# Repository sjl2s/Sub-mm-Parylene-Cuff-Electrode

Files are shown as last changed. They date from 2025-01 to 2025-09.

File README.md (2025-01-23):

# Sub-mm-Parylene-Cuff-Electrode
An electrode for interfacing with sub-mm diameter nerves for recording and stimulation, manufactured out of Parylene C
 # About

A nerve cuff for sub-millimeter diameter branch nerves designed and manufatured for CARSS by the [Biomedical Microsystems Lab at USC](https://biomems.usc.edu/). It is fabricated out of thin-film Parylene C with platinum electrodes and contacts, and contains a unique design and three dimensional geometry for surgical placement. The cuff is manufactured using thin-film Parylene C and platinum, followed by thermoforming into the desired shape.



Process flow diagram

# Disclaimer
The contents of this repository are subject to revision. No representation or warranty, express or implied, is provided in relation to the accuracy, correctness, completeness, or reliability of the information, opinions, or conclusions expressed in this repository.

The contents of this repository (the “Materials”) are experimental in nature and should be used with prudence and appropriate caution. Any use is voluntary and at your own risk.

The Materials are made available “as is” by USC (the University of Southern California and its trustees, directors, officers, employees, faculty, students, agents, affiliated organizations and their insurance carriers, if any), its collaborators Med-Ally LLC and Medipace Inc., and any other contributors to this repository (collectively, “Providers”). Providers expressly disclaim all warranties, express or implied, arising in connection with the Materials, or arising out of a course of performance, dealing, or trade usage, including, without limitation, any warranties of title, noninfringement, merchantability, or fitness for a particular purpose.

Any user of the Materials agrees to forever indemnify, defend, and hold harmless Providers from and against, and to waive any and all claims against Providers for any and all claims, suits, demands, liability, loss or damage whatsoever, including attorneys' fees, whether direct or consequential, on account of any loss, injury, death or damage to any person or (including without limitation all agents and employees of Providers and all property owned by, leased to or used by either Providers) or on account of any loss or damages to business or reputations or privacy of any persons, arising in whole or in part in any way from use of the Materials or in any way connected therewith or in any way related thereto.

The Materials, any related materials, and all intellectual property therein, are owned by Providers.

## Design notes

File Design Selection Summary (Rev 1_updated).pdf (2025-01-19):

# NEST 4 – Design Selection

Revised 22 June 2023

This document describes the design choices for the microfabricated cuff electrode. The lead (developed by Med-Ally) and insertion tool are not included in this document.

The document begins with design requirements and decisions made based on those requirements, follows with detailed mechanical design options and the selection process, and ends with an outline of planned testing (which will be further developed in Y2).

## 1 DESIGN REQUIREMENTS

The following design requirements were set for the microfabricated cuff design:

1. All materials must be biocompatible and have a history of chronic in vivo use
2. Cuff must fit a target nerve of 0.5-1.0 mm diameter
3. Cuff must wrap at least 1.5x around nerve diameter
4. Cuff must be self-sizing (within ranges below)
a. Small size: 0.5-0.8 mm diameter
b. Large size: 0.7-1.0 mm diameter
5. Electrodes must be spaced to allow for efficient stimulation
6. Electrodes and traces must be sized to allow for typical stimulation parameters (based on vagus nerve stimulation values)

To achieve each of these requirements, the following design decisions were made:

1.1 MATERIAL SELECTION
The microfabricated cuff is made of Parylene C as the backbone and insulation material and platinum as the conductive material. Both materials are compatible with existing, well-established microfabrication techniques, are biocompatible, and have been used extensively in chronic implants. The Med-Ally leads (as used in all NESTs and described in NEST 3) are made entirely of biocompatible materials and are attached to the microfabricated cuff either using a welding/bonding process (which does not add any additional material) or using biocompatible silver epoxy (Epo-TEK MED H20E). The connection point is insulated with medical grade silicone or epoxy.

1.2 CUFF DIMENSIONS
Helical electrodes and circumferential electrodes were considered. The electrode height (see figure below) for each cuff size was selected to allow the electrode to wrap 1.5 times around the largest nerve diameter in the size range. For helical electrode designs, the angle of the electrode was selected to ensure the cuff did not overlap itself (electrode turn gap > 0 in the figure below) when wrapped around any nerve diameter in the size range. The electrode width was defined by stimulation requirements (described later in this section).

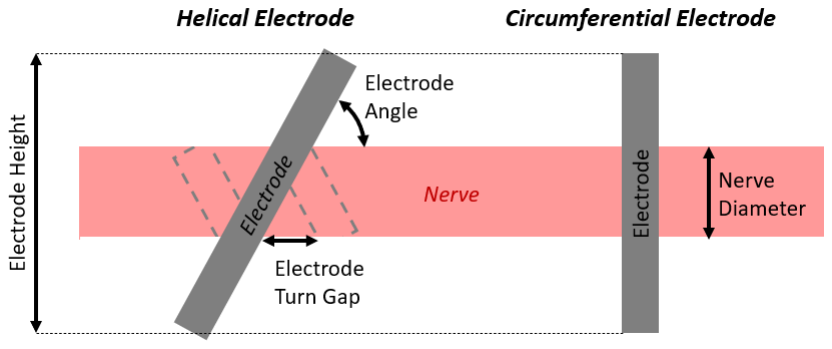
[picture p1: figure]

1.3 SELF-SIZING PROPERTY
The backbone material, Parylene C, is a thermoplastic polymer, allowing it to be thermoformed and permanently hold a 3D shape. Parylene C is also flexible, allowing it to be manually and temporarily flexed out of its formed shape. The microfabricated cuff electrode is thermoformed into a cuff shape matching the smallest diameter in the corresponding size range (i.e. 0.5 mm for small, 0.7 mm for large). After thermoforming, the cuff can be manually expanded to a larger size, then closes back to its original size when released. When expanded and placed on the nerve (with diameter greater than or equal to the cuff), the cuff closes until it contacts the nerve.

1.4 ELECTRODE SPACING
The distance between electrodes was set based on recommendations from experts in the field, literature on ideal electrode spacing, and geometry of existing larger cuff electrodes. In general, the ideal distance between electrodes is proportional to nerve diameter, so the electrode spacing found in the existing Liva Nova cuff (9 mm spacing for 2 mm diameter nerve) was scaled down to fit the target nerve diameters for the microfabricated cuff (3 mm spacing for 0.5-0.8 mm diameter nerve; 4 mm spacing for 0.7-1.0 mm diameter nerve).

1.5 ELECTRODE SIZE
The surface area of the electrodes was dictated by charge injection limits and desired stimulation parameters. Based on research summarized below, a charge storage capacity of 100 μC/cm² was used to calculate required electrode surface area. If this is not achieved with bare thin film Pt, electrode size can be later increased or charge storage capacity can be increased with surface treatments such as roughening, electroplating, or deposition of conductive polymers.
- Typical stimulation parameters for VNS
- 0.5-4.2 mA at 100 μs [1]
- 1.25-2.25 mA at 250 μs [2]
- 0.3-2.4 mA at 300 μs [1]
- 0.2-2.0 mA at 500 μs [1]
- Maximum allowable stimulation for LivaNova VNS: 3.5 mA, 1000 μs [3], [4]
- Charge injection capacity for platinum
- Foil

- 35-200 μC/cm²
[5]
- 50-100 μC/cm² at 0.2 ms (charge balanced biphasic) [6]
- Thin film
- 170 μC/cm² at 0.2 ms [7]
- 260 μC/cm² at 0.75-1.0 ms [7]
- Charge injection limits for tissue
- 50-100 μC/cm²
[internal recommendation]
- Shannon limit - dependent on electrode area [8]
- 200 μm circular electrode: 317 μC/cm²
- 600 μm x 2000 μm rectangular electrode: 51 μC/cm²

1.6 ELECTRODE SHAPE
Rather than using one large rectangular electrode, an array of closely packed, shorted microelectrodes was used. This prevents the high likelihood of cracking in the large electrode area during handling or stimulation by reducing the size of the large metal area and adding open areas in the electrode where the top and bottom Parylene layers can adhere to each other.

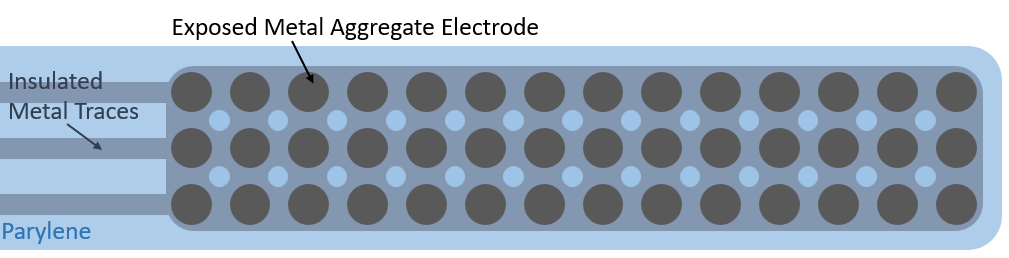
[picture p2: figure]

Based on the typical VNS parameters listed in the previous paragraph and a charge storage capacity of 100 μC/cm²
, the required electrode area and number of subelectrodes was calculated:
VNS Stimulation Parameters | Charge Per Phase | Required Electrode Area | Number of Microelectrodes
Amplitude | Pulse Width | | | 200 µm Diameter | 300 µm Diameter
4.2 mA | 100 µs | 0.42 µC | 0.42 mm² | 14 | 6
2.25 mA | 250 µs | 0.56 µC | 0.56 mm² | 18 | 8
2.4 mA | 200 µs | 0.72 µC | 0.72 mm² | 23 | 11
2.0 mA | 500 µs | 1.00 µC | 1.00 mm² | 32 | 15

The maximum values (italicized) were used to select the number of microelectrodes, and a safety factor of at least 1.5 was used.

For helical electrodes, a width of 3 and 4 microelectrodes (small and large sizes) was selected as it allows for a moderate helix angle (55°) without any electrode overlap at the smallest nerve size and produces sufficient electrode area when wrapped ~1.5x around the nerve.

- Small cuff (0.5-0.8 mm dia): 3x18 200 μm microelectrodes (1.70 mm²
total area)
- Large cuff (0.7-1.0 mm dia): 4x22 200 μm microelectrodes (2.77 mm² total area)

For circumferential electrodes, the minimum nerve circumference dictated the electrode layout (electrodes were wider due to the overlapping arms of the electrodes blocking part of the stimulation area).

- Small cuff (0.5-0.8 mm dia): 9x14 200 μm microelectrodes (1.70 mm²

total area, 1.56 mm²
contact area with smallest nerve)
- Large cuff (0.7-1.0 mm dia): 6x18 200 μm microelectrodes (3.39 mm²

total area, ~1.60 mm² area in contact with smallest nerve)

1.7 TRACE WIDTH
The minimum allowable trace width (to prevent overheating) was dictated by maximum current requirements and calculated using a PCB trace width calculator (with formulas sourced from IPC-2221). A total minimum trace width of 72 µm was calculated (from parameters: 4.2 mA, 200 nm trace thickness, 10 °C rise at 37 °C ambient temperature). Four connected, parallel 36 µm traces with intermittent bridges between them are used to maintain device flexibility and add in a safety factor of 2, still with sufficient width if two traces are broken.

## 2 MECHANICAL DESIGN OPTIONS

There are numerous mechanical designs which would meet the device requirements. Several experts in the field stated no preference on backbone and electrode shape for surgical, anatomical, or electrochemical considerations. To select a mechanical design, several designs were fabricated and tested to determine the best option for fabrication, surgical handling, and potential failure modes. The design options are described in this section; details on the fabricated designs and testing protocol is described later in this document.

The microfabricated cuff has three regions: the backbone, the tail, and the lead. As shown in the image below, the backbone is the main body of the device which holds the electrodes and forms the cuff architecture, the tail extends from the backbone and connects the electrodes to the lead with insulated traces, and the lead attaches to the traces at the end of the tail at the lead attachment point.

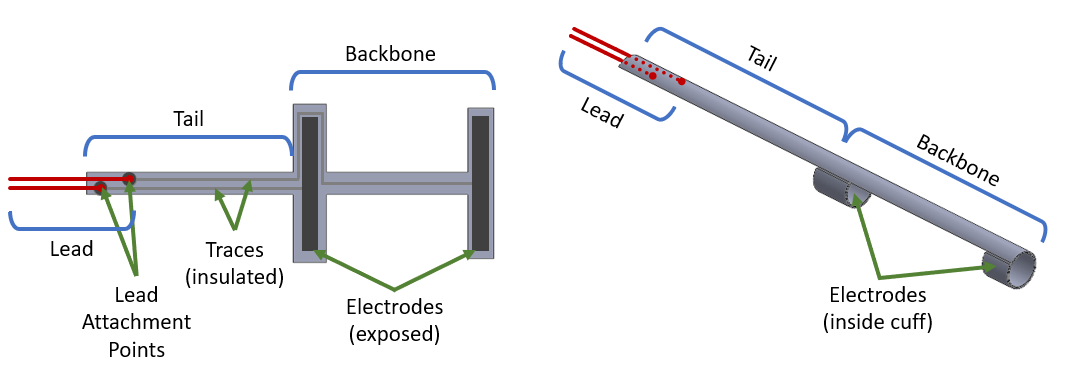
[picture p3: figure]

Note: In all images in the remainder of this section, the shape of the flat electrode array (as it is fabricated) is shown on the left, and the electrode array after thermoforming into shape is shown on the right. Only the Parylene is shown in these images, the electrodes are not drawn in.

2.1 PARYLENE BACKBONE DESIGNS
The Parylene backbone is the main part of the device which supports the electrodes. It is microfabricated in a flat configuration on a carrier wafer and then thermoformed into the cuff shape. The considered designs are shown here with basic notes pointing out their main features.

Note: the images in this section only show the backbone portion of the device, not the tail portion.

2.1.1 Design A: U-Shaped
Design A not considered for final design
- Dual helical cuff (opposite directions)
| ○ Similar to design B, but with center Parylene bridge at the bottom of the electrodes
2.1.2 | Design B: I-Shaped (tilted, opposite)
- Dual helical cuff (opposite directions)
- 360°+ electrode coverage over a ~1.5-3 mm span (single helical cuff width)

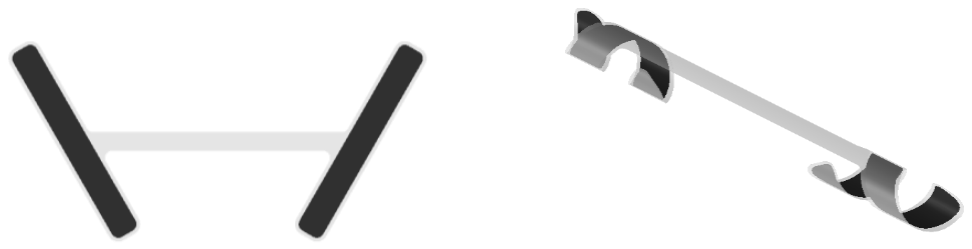
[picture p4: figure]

2.1.3 Design C: I-Shaped (tilted, same)
- Dual helical cuff (same direction)
- 360°+ electrode coverage over a ~1.5-3 mm span (single helical cuff width)

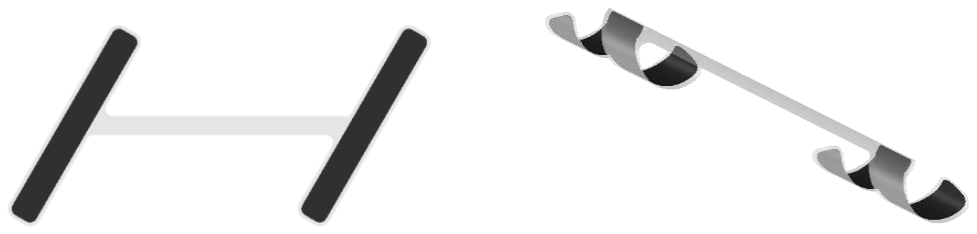
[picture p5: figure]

2.1.4 Design D: I-shaped (straight)
- Dual circumferential cuff
- ~335° electrode coverage over a ~0.5-1 mm span (electrode width)

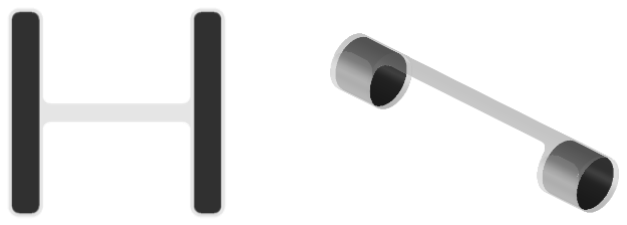
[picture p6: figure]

2.1.5 Design E: Full cuff
- Single circumferential cuff with 2 isolated electrodes
- ~355° electrode coverage over a ~0.5-1 mm span (electrode width)

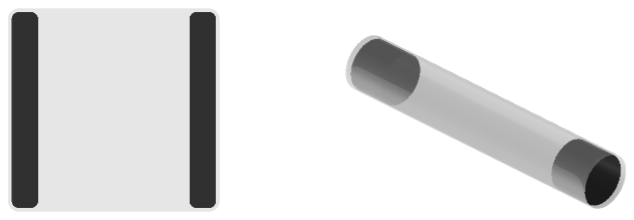
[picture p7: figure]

2.2 CABLE ROUTING DESIGNS
To connect the electrodes to the lead, a tail must be attached to the backbone to connect metal traces from each electrode to a bondpad which connects to the lead. The tail must have some length (~2 cm) and slack to allow for motion during the implantation procedure and any motion of the nerve relative to the point where the lead is anchored. The considered tail options are listed here with some potential issues and advantages.

Note: All cable options are shown on backbone design B, but can be applied to any design

2.2.1 Tail 1: End
Tail 1 not considered for final design
- Tail extending straight from one end
- No strain relief or slack

2.2.2 Tail 2: Centered
- Any torque on tail will be centered on cuff
- Difficult to implement with fins or full cuff designs

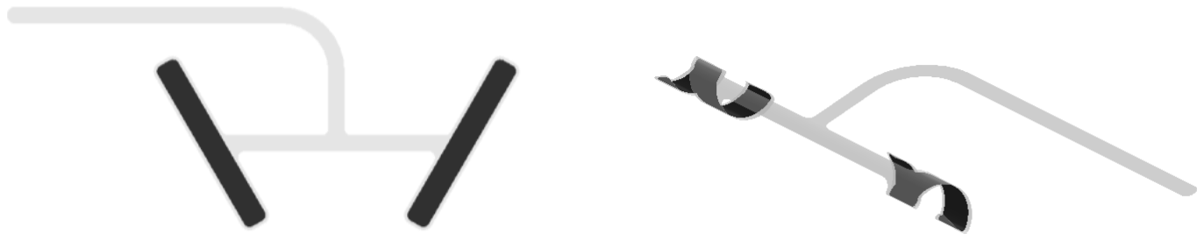
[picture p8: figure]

2.2.3 Tail 3: U-turn
- Prevents torque by adding more slack (service loop)

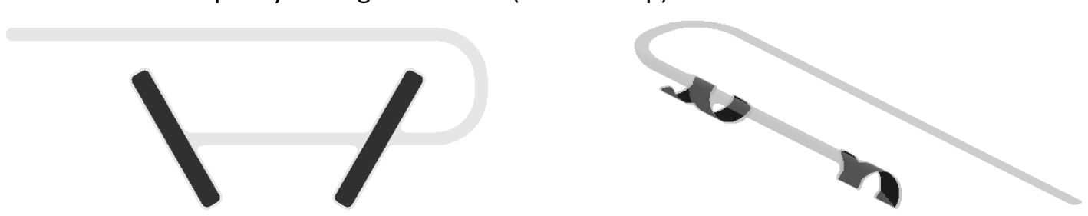
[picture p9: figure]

2.2.4 Optional Serpentine Strain Relief
- Auxetic structure to allow stretching
- Could be added at any point in the tail

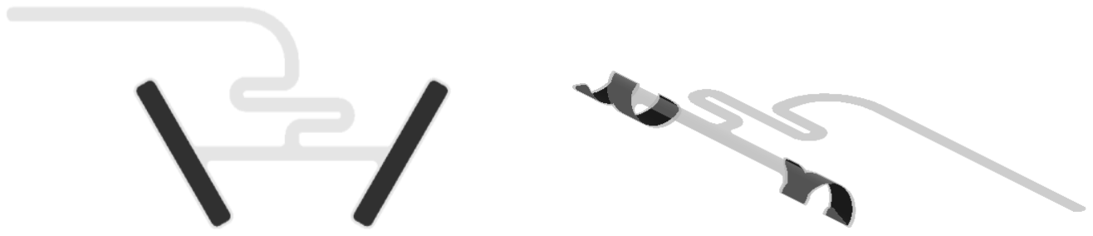
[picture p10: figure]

2.3 NERVE INSULATION
Insulation of the nerve between the electrodes is critical to constrain the electric field during stimulation. Insulation can be done either with Parylene (fabricated with the rest of the cuff) or PDMS (either a separate cuff added at the end or molded onto the Parylene backbone). Several options (listed here) were considered for nerve insulation.

2.3.1 Solid Parylene
- Design E: Full cuff

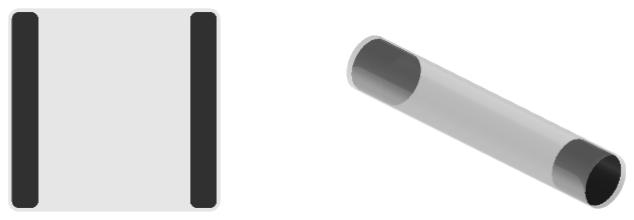
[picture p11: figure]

2.3.2 Parylene Fins
- Designs A-D: Parylene fins added between electrodes
- More mechanically flexible than solid Parylene cuff
- E-field leakage between the fins

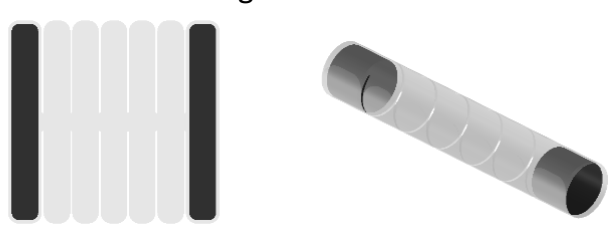
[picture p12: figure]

2.3.3 PDMS Insulation
- Separate molded PDMS cuff (can be attached to Parylene or added separately after
| implantation)
- PDMS can be solid (with any Parylene design) or with fins (with designs A-D)
- E-field leakage if fins are used

## 3 MECHANICAL DESIGN SELECTION

3.1 DESIGNS TO TEST
The large number of design combinations could not be exhaustively tested, so a subset of 8 designs which spanned all backbone shapes, tails, and other features were selected. Designs are numbered using the following component labels (crossed out designs were not considered):
Backbone | Tail | Other Feature
(A) U-shaped | (1) End | (s) serpentine strain relief
(B) I-shaped (tilted/opposite) | (2) Centered | (f) fins
(C) I-shaped (tilted/same) | (3) U-turn | (-) none
(D) I-shaped (straight)
(E) Full cuff

The following designs were tested:

- B2-: I-shaped/tilted/opposite, centered tail
- B2s: I-shaped/tilted/opposite, centered tail with serpentine
- C2-: I-shaped/tilted/same, centered tail
- C3-: I-shaped/tilted/same, u-turn tail
- D2-: I-shaped/straight, centered tail
- D2f: I-shaped/straight with fins, centered tail
- D3f: I-shaped/straight with fins, u-turn tail
- E3-: Full cuff, u-turn tail

To evaluate backbone shape, compare: B2- vs. C2- vs. D2- vs. E3-

To evaluate tails, compare: C2- vs C3- and D2f vs D3f

To evaluate serpentine strain relief, compare: B2- vs B2s

To evaluate fins, compare: D2- vs D2f

3.2 DESIGN SELECTION PROTOCOL
The following testing protocol was used to rank each design and each component. 6 parts for each design were tested (n=6). Steps that may improve with repetition (fixturing for thermoforming, implanting) were tested in varying order for each iteration. Tests which were recorded and scored are labeled and bolded within the protocol.

3.2.1 Thin Film Fabrication
1. Fabricate dummy parts (no metal) using standard thin film processing
2. Using varying base layer annealing conditions (impacts the curvature of the device prior to
| thermoforming)
a. 60, 100, and 150 °C
b. Two parts for each annealing condition (total n=6) were processed in all remaining steps

3.2.2 Thermoforming
1. Release the parts from the carrier wafer
2. Fixture into a 0.5 mm cuff and thermoform at 200 °C for 12 hours
a. Test 1 (Fabrication Difficulty): Record the amount of time required to release the device
| from the wafer and fixture for thermoforming
i. A single trained operator thermoformed all parts within each annealing group to
| prevent data errors from variability between operators ii. Captures if any device geometries are difficult to work with
3. Remove parts from fixture

3.2.3 Visual Inspection
1. Inspect parts using a stereoscope (best magnification to visualize the full device - same scope
| and magnification was used for all devices)
2. Test 2a (Post-Thermoform Inspection - Shape): Calculate the fabrication yield for all devices of a
| given design, where devices that do not hold the fixtured shape are failures
a. Determines if any geometries are prone to thermoforming shape failures
3. Inspect parts using a 10x microscope at each of the inspection points shown below

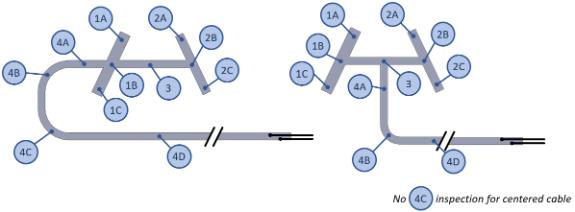
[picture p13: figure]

4. Test 2b (Post-Thermoform Inspection - Cracking): Count the total length of cracks in the Parylene in a 0.25x0.25 mm square area at each inspection point
a. Determines if any geometries are more prone to cracking during fabrication and at what location cracks are more common
b. Balances any errors in test 1 (i.e. if a part is fixtured quickly but badly, the good score in test 1 will be balanced by a bad score in test 2)

3.2.4 Evaluate Opening Force
1. Fixture parts with one end of cuff secured to load cell and one end secured to a micrometer
| stage
2. Use wires to fixture parts such that the cuff is able to open and close as it will in the
| implantation tools
3. Adjust the micrometer such that the cuff is opened to a 0.5 mm width (the thermoformed size)
| where the opening force is zero
4. Expand the cuff using the micrometer to 0.8, 1.2, 1.6, and 2.4 mm
5. Test 3a (Opening Force - Preliminary): Measure the force required to open the cuff to each of
| the listed micrometer readings
a. Proxy for cuff pressure measurements (pressure measurement setup not available at
| the time of testing)

6. Return the cuff to its closed form (0.5 mm), open to 2.4 mm, then close to 0.5 mm; repeat 18x (including the first measurement, this will be 19 cycles)
7. Expand the cuff using the micrometer (20th cycle) to 0.8, 1.2, 1.6, and 2.4 mm
8. Test 3b (Opening Force - Cycled): Measure the change in force required to open the cuff to each of the listed micrometer readings as compared to the first cycle
a. Proxy for cuff pressure measurements (pressure measurement setup not available at the time of testing)

3.2.5 Implant Cuff
1. Mount cuff onto an interim implantation tool (tweezers modified with wires)
a. Place cuff on flat surface
b. Close tweezers and thread tweezer tips into the center of the cuff
c. Open tweezers and align over nerve
d. Lower tweezers and close below the nerve, placing cuff
e. Retract tweezers out of cuff, open, and pull away from nerve
f. Adjust cuff (if needed) to close snugly around nerve
2. “Implant” (place) cuff onto a dummy nerve
a. For the dummy nerve, use a wet/overcooked rice noodle ~0.7-0.9 mm in diameter
b. Hold dummy nerve between two supports suspended 1 mm above a flat surface to
| simulate allowable space during surgery
3. Test 4 (Implantation Difficulty): Rank the devices from least to most difficult to implant
| * Note: The initial plan was to record the time required to implant the device, however timing was not consistent with the interim implantation tool, so a ranked qualitative comparison was used instead – see Appendix for details on testing * Note: This test was only performed on one set of devices – it did not accurately represent implantation difficulty because the surgical tool has not yet been developed and the interim tool was not consistent in use
a. Will capture if any device geometries are relatively more difficult to implant
b. A single trained operator performed the simulated implant on all parts within each
| annealing group to prevent data errors from variability between operators
3.2.6 | Simulate Body Movement
1. Simulate stress on device during surgery by pulling tail perpendicular and parallel to the nerve
2. Simulate stress on device during body movement by stretching the nerve along and
| perpendicular to its length
3. Test 5 (Cuff Movement): Measure the distance the cuff moves during the simulated stress
| * Note: Due to difficulties in performing test 4, cuff movement was observed qualitatively instead of quantitatively; quantitative measurements will be taken with future device generations once a more reliable surgical tool has been developed * Note: This test was only performed on one set of devices due to the constraint with the implantation tool described under test 4
a. Determines if any device geometries are prone to shifting out of place during or after
| implantation

3.2.7 Repeat Visual Inspection
1. Test 6a (Post-Implantation Inspection - Shape): Calculate the shape yield for all devices of a
| given design, where devices that do not hold the fixtured shape are failures
a. Determines if any geometries are prone to shape failures during surgical handling
2. Test 6b (Post-Implantation Inspection - Cracking): Count the total length of cracks in the
| Parylene in a 0.25x0.25 mm square area at each inspection point, and subtract the initial inspection length from test 2b
a. Determines if any geometries are more prone to cracking during surgical handling

3.2.8 Failure Testing
1. Mount cuff on nerve underneath the load cell, then pull the tail end perpendicular to the nerve
| until failure (n=2 per design)
2. Test 7a (Pull Failure - Perpendicular): Measure the force at failure and record the failure point
3. Mount cuff on nerve underneath the load cell, then pull the tail end parallel to the nerve in the
| direction of the tail until failure (n=2 per design)
4. Test 7b (Pull Failure - Parallel): Measure the force at failure and record the failure point

3.3 SCORE CALCULATIONS
Results of each test were scaled to produce a score from 0 to 1 for each tested device and each design component, with 0 being the worst score and 1 being the best score. Tests were also weighted, with higher weights given to more important or more significant tests. Details of how scores were calculated and weights were selected are below:

Test 1: Fabrication Difficulty

Design Score = 1 −

| avg fixturing time (single design) − min fixturing time (all parts) max fixturing time (all parts) − min fixturing time (all parts)

Note: parts with fixturing times more than 2 standard deviations above the mean were considered outliers and not used for score calculations

Test 2a: Post-Thermoform Inspection – Shape

| Design Score = yield (single design)

Test 2b: Post-Thermoform Inspection – Cracking

| Design Score (max cracks) = 1 −

max cracks per area (single design) max cracks per area (all parts)

| Design Score (avg cracks) = 1 −

avg cracks per area (single design) max cracks per area (all parts)

| Design Score = Design Score (max cracks) + Design Score (avg cracks)
2

Test 3a: Opening Force – Preliminary

Design Score (X mm opening)

= 1 −

avg force @ X mm (single design) − min force @ X mm (all parts) max force @ X mm (all parts) − min force @ X mm (all parts)

Design Score

=

Design Score (0.8 mm) + Design Score (1.2 mm) + Design Score (1.6 mm) + Design Score (2.4 mm) 4

Test 3b: Opening Force – Cycled

Design Score (X mm opening)

= 1 −

avg force decrease @ X mm (single design) − min force decrease @ X mm (all parts) max force decrease @ X mm (all parts) − min force decrease @ X mm (all parts)

Design Score

=

Design Score (0.8 mm) + Design Score (1.2 mm) + Design Score (1.6 mm) + Design Score (2.4 mm) 4

Test 4: Implantation Difficulty

Design Score = 1 −

ranking (single design) − ℎigℎest rank (all parts) ℎigℎest rank (all parts)

Test 5: Cuff Movement

Design Score = 1 −

avg movement distance (single design) max movement distance (all parts)

Test 6a: Post-Implant Inspection – Shape

Design Score = yield (single design)

Test 6b: Post-Implant Inspection – Cracking

Design Score (max cracks) = 1 − max cracks per area (single design) max cracks per area (all parts)

Design Score (avg cracks) = 1 − avg cracks per area (single design) max cracks per area (all parts)

Design Score =

Design Score (max cracks) + Design Score (avg cracks) 2

Test 7a: Pull Failure – Perpendicular

Design Score =

avg failure force (single design) − min failure force (all parts) max failure force (all parts) − min failure force (all parts)

Test 7b: Pull Failure – Parallel

Design Score =

avg failure force (single design) − min failure force (all parts) max failure force (all parts) − min failure force (all parts)

3.3.1 | Test Weights
| Test | Weight
1 | Fabrication Difficulty | 1
2a | Post-Thermoform Inspection – Shape | 1
2b | Post-Thermoform Inspection – Cracking | 3
3a | Opening Force – Preliminary | 2
3b | Opening Force – Cycled | 1
4 | Implantation Difficulty | 1
5 | Cuff Movement | 0*
6a | Post-Implant Inspection – Shape | 1
6b | Post-Implant Inspection – Cracking | 3
7a | Pull Failure – Perpendicular | 2
7b | Pull Failure – Parallel | 2
* no movement was observed qualitatively, so test 5 was not considered for design selection

3.4 DESIGN SELECTION RESULTS
The design selection protocol was performed on n=6 parts for each design and yielded the following results. Full dataset is included as a separate attachment.
Test | Tested Designs
B2- | B2s | C2- | C3- | D2- | D2f | D3f | E3-
1 (Fab Difficulty) | 0.58 | 0.74 | 0.59 | 0.74 | 0.85 | 0.81 | 0.65 | 0.85
2a (Post TF Shape) | 1.00 | 1.00 | 1.00 | 1.00 | 1.00 | 0.86 | 1.00 | 1.00
2b (Post TF Cracking) | 0.86 | 0.49 | 0.53 | 0.74 | 0.57 | 1.00 | 0.75 | 0.71
3a (Prelim Force)
3b (Cycled Force)
4 (Implant Difficulty) | 0.43 | 0.29 | 0.43 | 0.57 | 0.71 | 0.00 | 0.14 | 0.86
5 (Movement) | 1.00 | 1.00 | 1.00 | 1.00 | 1.00 | 1.00 | 1.00 | 1.00
6a (Post Implant Shape)
6b (Post Implant Cracking)
7a (Perpendicular Failure)
7b (Parallel Failure)
Weighted Aggregate | 0.76 | 0.58 | 0.60 | 0.76 | 0.71 | 0.78 | 0.68 | 0.81

Although these scores indicate that E3- and D2f performed best, this list of designs is not exhaustive, and the component scores should be considered to select the best design.

Scores were compared and separated for each design component (backbone shape, tail shape, other features, and annealing temperature) to produce component scores:

Test | Backbone Shapes
B | C | D | E
1 (Fab Difficulty) | 0.58 | 0.67 | 0.85 | 0.85
2a (Post TF Shape) | 1.00 | 1.00 | 1.00 | 1.00
2b (Post TF Cracking) | 0.85 | 0.65 | 0.57 | 0.71
3a (Prelim Force)

3b (Cycled Force)
4 (Implant Difficulty) | 0.43 | 0.50 | 0.71 | 0.86
5 (Movement) | 1.00 | 1.00 | 1.00 | 1.00
6a (Post Implant Shape)
6b (Post Implant Cracking)
7a (Perpendicular Failure)
7b (Parallel Failure)
Weighted Aggregate | 0.76 | 0.69 | 0.71 | 0.80
Test | Cable Routing
2 3
1 (Fab Difficulty) | 0.69 | 0.69
2a (Post TF Shape) | 0.92 | 1.00
2b (Post TF Cracking) | 0.54 | 0.94
3a (Prelim Force)
3b (Cycled Force)
4 (Implant Difficulty) | 0.21 | 0.36
5 (Movement) | 1.00 | 1.00
6a (Post Implant Shape)
6b (Post Implant Cracking)
7a (Perpendicular Failure)
7b (Parallel Failure)
Weighted Aggregate | 0.57 | 0.81
Test | Other Features
-(s) | s | -(f) | f
1 (Fab Difficulty) | 0.58 | 0.74 | 0.85 | 0.81
2a (Post TF Shape) | 1.00 | 1.00 | 1.00 | 0.86
2b (Post TF Cracking) | 0.86 | 0.49 | 0.57 | 1.00
3a (Prelim Force)
3b (Cycled Force)
4 (Implant Difficulty) | 0.43 | 0.29 | 0.71 | 0.00
5 (Movement) | 1.00 | 1.00 | 1.00 | 1.00
6a (Post Implant Shape)
6b (Post Implant Cracking)
7a (Perpendicular Failure)
7b (Parallel Failure)
Weighted Aggregate | 0.76 | 0.58 | 0.71 | 0.78
Test | Base Anneal
60°C | 100°C | 150°C
1 (Fab Difficulty) | 0.84 | 0.87 | 0.49
2a (Post TF Shape) | 1.00 | 0.94 | 1.00
2b (Post TF Cracking) | 0.49 | 0.75 | 0.65

3a (Prelim Force)
3b (Cycled Force)
4 (Implant Difficulty) | n/a | n/a | n/a
5 (Movement)
6a (Post Implant Shape)
6b (Post Implant Cracking)
7a (Perpendicular Failure)
7b (Parallel Failure)
Weighted Aggregate | 0.66 | 0.81 | 0.69

These preliminary scores show that all backbones performed similarly, with B and E slightly outperforming the others. Tail 3 significantly outperformed tail 2, with the serpentine strain relief decreasing scores. Fins improved scores for fabrication steps (tests 1 and 2) but was the most difficult to implant (test 4). Parts with a 100 °C base anneal (moderate curl) performed better than those with high temperature anneal (high curl) or no anneal (flat).

Based on these results, two backbone shapes have been tentatively selected:

1. B3-: I-shaped (tilted, opposite) with u-turned tail
2. E3-: Full cuff with u-turned tail

When testing is completed, the final selections will be re-evaluated.

The curvature due to the base anneal used in these test parts (towards the base layer) was calculated using the model described in Thielen and Meng 2023 [9]. In the functional parts, we are aiming for curvature in the opposite direction (curling towards the top layer) so that the exposed metal will be in contact with the nerve. This curvature is accomplished by adjusting the ratio of the base to top layer thickness. The following parameters were used for this calculation:

Parameter | Value (Test Parts) | Value (Real Parts)
Base Parylene Width | 1200 µm | 880 µm
Top Parylene Width | 1200 µm | 580 µm * average of 280 µm width across microelectrode openings and 880 µm width between microelectrode openings
Total Parylene Thickness | 8.6 µm | 10 µm * Thickest that will not crack when thermoformed to 0.5 mm diameter
Base to Top Parylene Thickness Ratio (variable) | 3.33:5.27 | 3:7 to 7:3 * Minimum Parylene thickness of 3 µm to ensure good insulation
Parylene Stress | 7.8 MPa (at 90 °C) 9.4 MPa (at 100 °C) 17.5 MPa (at 150 °C | 7.8 MPa

| * From fit data 90 °C (highest fabrication processing temperature), 100 °C, and 150 °C in Thielen and Meng 2023 | * From fit data at 90 °C (highest fabrication processing temperature) in Thielen and Meng 2023
Metal Width | 0 | 568 µm * average of 760 µm width across microelectrode openings and 376 µm width between microelectrode openings
Metal Thickness | 0 | 220 nm * 20 nm Ti + 25 nm Pt + 150 nm Au + 25 nm Pt
Metal Stress | 0 | -100 MPa * From fit data in Thielen and Meng 2023

This yields the following results:

Base Anneal (Test Parts) | Curvature Diameter (Test Parts) | | Curvature Diameter (Real Parts) | Parylene Thicknesses (Real Parts)
60 °C | Flat | → | Flat | 4.5 µm base 5.5 µm top
100 °C | -21 mm | → | 21 mm | 4 µm base 6 µm top
150 °C | -3.5 mm | → | 7.5 mm * minimum diameter within constraints | 3 µm base 7 µm top

## 4 FINAL DESIGN SUMMARY

Electrode Size:

- Small/helical cuff: 3x18 200 μm microelectrodes (1.70 mm² total area)
- Large/helical cuff: 4x22 200 μm microelectrodes (2.77 mm²
total area)
- Small/circumferential cuff: 9x14 200 μm microelectrodes (1.70 mm²

total area, 1.56 mm²
contact area with smallest nerve)
- Large/circumferential cuff: 6x18 200 μm microelectrodes (3.39 mm²

total area, ~1.60 mm² area in contact with smallest nerve)

Backbone Shape (two options):

- I-shaped, tilted, opposite directions with u-turned tail
- Full cuff with u-turned tail

Parylene Thickness:

- 4 µm base + 6 µm top (promotes mild curvature towards top layer)

Mask Design:

- 4x36 µm traces to each electrode, connected at periodic intervals
- 36 µm gap between traces
- 20 µm or greater gap between all metal edges and Parylene edges (i.e. metal edge is insulated by at least 20 µm wide Parylene)

CAD files (3D model and 2D mask layout) are available as a separate document.

## 5 ATTACHMENT FROM LEAD TO PARYLENE

Med-Ally is working to develop a process to attach the Parylene cuff to their leads. This will be completed in Y2. In the interim, the leads (or other wires for benchtop testing) can be attached to the traces of the Parylene cuff using conductive silver epoxy (Epo-TEK MED H20E)

## 6 TESTING

A battery of tests will be used to ensure the parts are working as designed on the benchtop and in vivo. Detailed testing plans will be developed in Y2, but the section below outlines the tests that will be included.

6.1 VISUAL INSPECTION
- Optical microscopy
- Electron microscopy

6.2 MECHANICAL TESTING
- T-peel testing (adhesion strength)
- Motion of nerves
- Nerve phantom in matrix on shaker table
- Nerve compression
- Requirements: <20 mm Hg pressure (chronic), <80 mm Hg pressure (acute)

6.3 ELECTRICAL TESTING
- Identify defects (shorts/cracks)
- Leakage (insulation integrity)

6.4 ELECTROCHEMICAL TESTING
- Cyclic voltammetry (CV): determine charge storage capacity, electrode surface area
- Electrochemical impedance spectroscopy (EIS): determine electrode impedance, device integrity
- Cross talk: determine insulation integrity, defects

6.5 ACCELERATED LIFETIME TESTING
- Saline with reactive oxygen species
- Repeat visual and electrochemical testing

## 7 TIMELINE

Y1 | Q4 | Aug 2023 | Complete first design of microfabricated cuff (documentation and prototype)
Y2 | Q2 | Feb 2023 | Complete first design of surgical placement tool (documentation and prototype)
| | | Develop test procedures and performance metrics
Q4 | Aug 2024 | Demonstrate benchtop reliability of cuff and placement tool
Y3 | Q1 | Nov 2024 | Release feature-complete documentation and open-source libraries

Establish collaborations with other HORNET teams

Q4 | Aug 2025 | Complete evaluation of cuff and placement tool

## 8 APPENDIX: TEST 4 / IMPLANTATION DIFFICULTY

After the successful microfabrication of the Parylene device, a preliminary implantation test on a nerve-like model was performed. Overcooked wet noodles were used owing to their physical properties being close to nerves and being in the sub-mm range.

A noodle is elevated by two glass slides at its extremities. The Parylene device is opened by a tweezer extended by one straight metal wire at each handling tip. Then it is put on the noodle before cuffing it when retracting the two wires from the device.

The goal of this preliminary approach is to assess all the main parameters to properly place the device and to sort all the different designs according to the placement difficulty.

Several parameters were retained to appraise the placement difficulty.

1. Wire placement: The two wires must be perfectly joined without crossing each other. In this case, the two wires couldn’t enter the cuff.
2. Device orientation: A particular heed should be paid to ensure that the cuff is open in the correct position, facing down.
3. Opening range trade-off: Large cuff opening enable an easier placement but increases the chance that the cuff goes out of the wires.
4. Incomplete cuffing: When placed on the noodle, part of the backbone can be partially folded, preventing the cuff from perfectly cuffing the nerve.

Each of the 8 fabricated designs were evaluated.

Evaluation by their backbones:

- B and C are quite equivalent during the placement procedure. Their main issue is that they easily create partial folding, and the end of the cuff does not fully cuff the noodle.
- D is equivalent to B and C but tends to not create partial folding.
- Df is difficult to operate when trying to open it as some fins easily go out from the wire.
- E is the least difficult one to place.

Evaluation by their tail:

As we must hold the device by its extremities when placing the wires, a 3 U-turn tail is much more practical than a 2-centered tail generally. But this observation is only linked to this placement procedure which is not optimal yet.

Sorting from the easiest to place to the most difficult:

1. E3-: Full cuff, u-turn tail
2. D2-: I-shaped/straight, centered tail
3. C3-: I-shaped/tilted/same, u-turn tail
4. C2-: I-shaped/tilted/same, centered tail, B2-: I-shaped/tilted/opposite, centered tail
5. B2s: I-shaped/tilted/opposite, centered tail with serpentine
6. D3f: I-shaped/straight with fins, u-turn tail
7. D2f: I-shaped/straight with fins, centered tail

## 9 REFERENCES

[1] B. Koo, S. D. Ham, S. Sood, and B. Tarver, “Human vagus nerve electrophysiology: A guide to vagus nerve stimulation parameters,” J. Clin. Neurophysiol., vol. 18, no. 5, pp. 429–433, 2001, doi: 10.1097/00004691-200109000-00007.
[2] J. W. Wheless, A. J. Gienapp, and P. Ryvlin, “Vagus nerve stimulation (VNS) therapy update,” Epilepsy Behav., vol. 88, pp. 2–10, 2018, doi: 10.1016/j.yebeh.2018.06.032.
[3] “Physician’s Manual VNS Therapy Generator and Lead Manual for Depression.” LivaNova USA, Inc., Houston, TX, 2022.
[4] “Physician’s Manual VNS Therapy Generator and Lead Manual for Epilepsy.” LivaNova USA, Inc., Houston, TX, 2022.
[5] S. F. Cogan, K. A. Ludwig, C. G. Welle, and P. Takmakov, “Tissue damage thresholds during therapeutic electrical stimulation,” J. Neural Eng., vol. 13, no. 2, 2016, doi: 10.1088/1741-2560/13/2/021001.
[6] T. L. Rose and L. S. Robblee, “Electrical Stimulation with Pt Electrodes. VIII. Electrochemically Safe

Charge Injection Limits with 0.2 MS Pulses,” IEEE Trans. Biomed. Eng., vol. 37, no. 11, pp. 1118– 1120, 1990, doi: 10.1109/10.61038.

[7] A. N. Ivanovskaya et al., “Electrochemical Roughening of Thin-Film Platinum for Neural Probe Arrays and Biosensing Applications,” J. Electrochem. Soc., vol. 165, no. 12, pp. G3125–G3132, 2018, doi: 10.1149/2.0171812jes.
[8] R. V Shannon, “A model of safe levels for electrical stimulation,” IEEE Trans. Biomed. Eng., vol. 39, no. 4, pp. 424–426, 1992.
[9] B. Thielen and E. Meng, “Characterization of thin film Parylene C device curvature and the formation of helices via thermoforming,” J. Micromechanics Microengineering2, 23AD, doi: 10.1088/1361-6439/acdc33.

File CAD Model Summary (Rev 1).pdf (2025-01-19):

### NEST 4 Microfabricated Cuff - CAD Models

Updated 24 July 2023

For each selected design (B3- and E3-), a 2D mask layout and 3D rendering are included. Full CAD files will be available on GitHub.

The image below shows a labeled sample of a 2D layout with critical dimensions labeled. The bondpad region (at the end of the tail) is likely to change after the development of the lead attach process by Med-Ally in year 2.

Light gray features are the Parylene backbone. Medium gray features are insulated metal (sandwiched between two Parylene layers). Dark gray features are exposed metal (with Parylene on the backside and no Parylene on the top side).

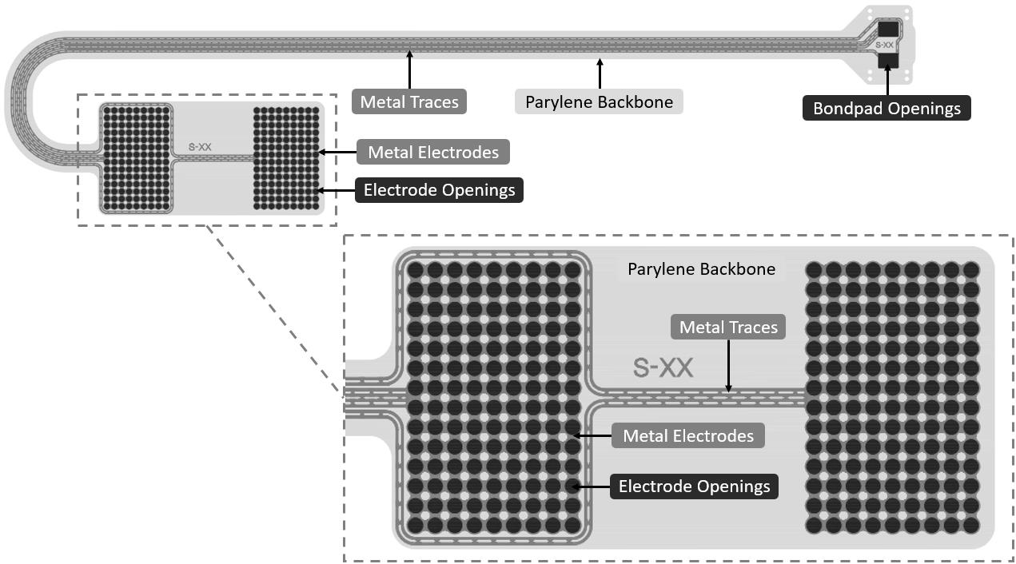
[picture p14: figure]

All images shown in the sections below are similar to the one above, but unlabeled. The colors represent three layers of the 2D CAD model. These layers are shown separately in the image below for clarity but are not included for each model in this document. CAD files on GitHub include all layers separately. The three layers represent the three masks:

Mask 1: Metal features

Mask 2: Electrode openings and device edges (edges not shown in the image below)

Mask 3: Device edges only

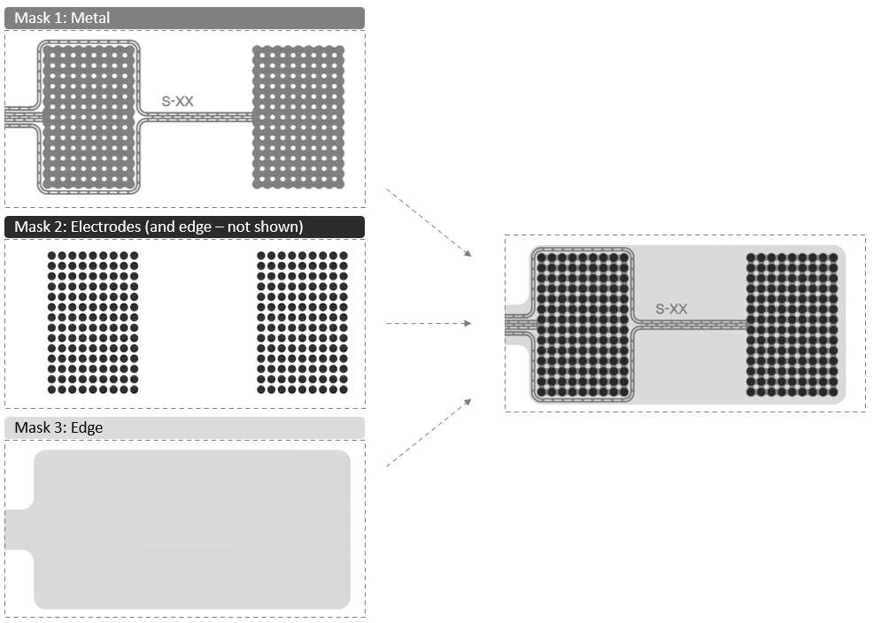
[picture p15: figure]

Below the 2D layout, a 3D rendering of the device is shown. The 3D model shows the overall device shape (only the Parylene backbone, no electrodes or other metal is included).

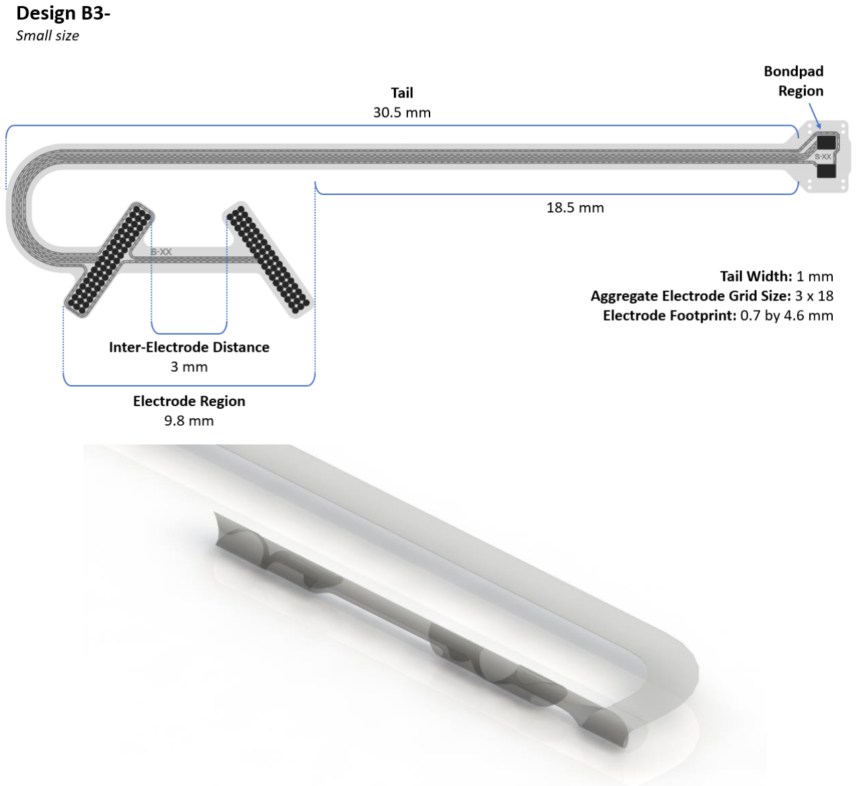
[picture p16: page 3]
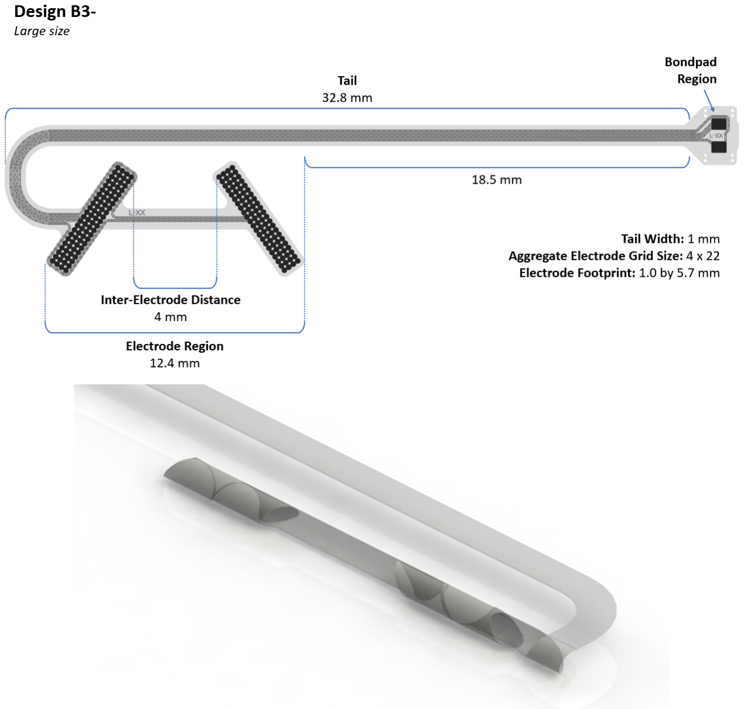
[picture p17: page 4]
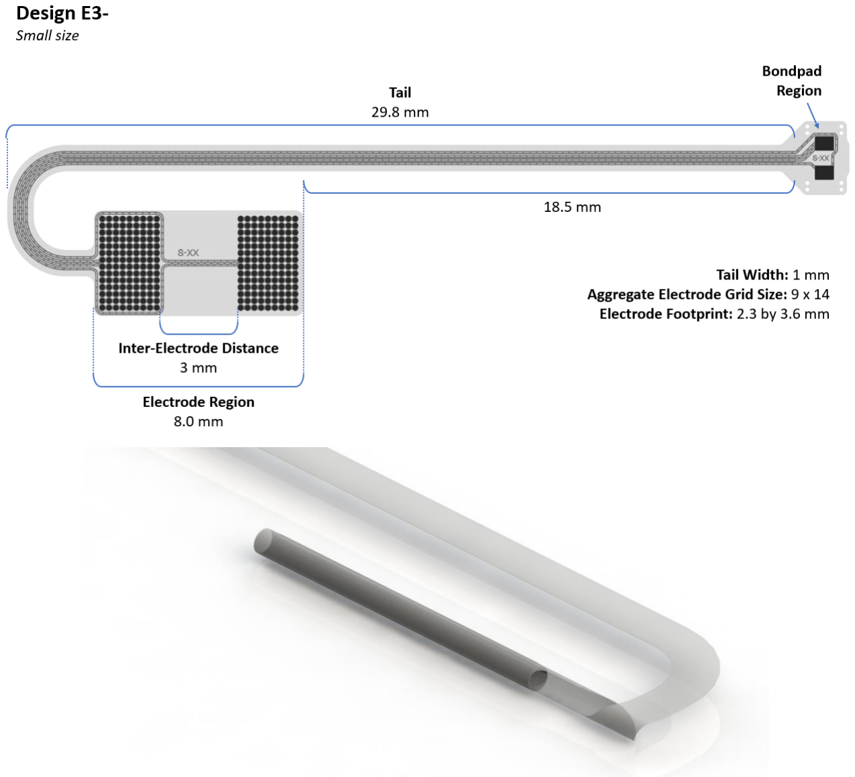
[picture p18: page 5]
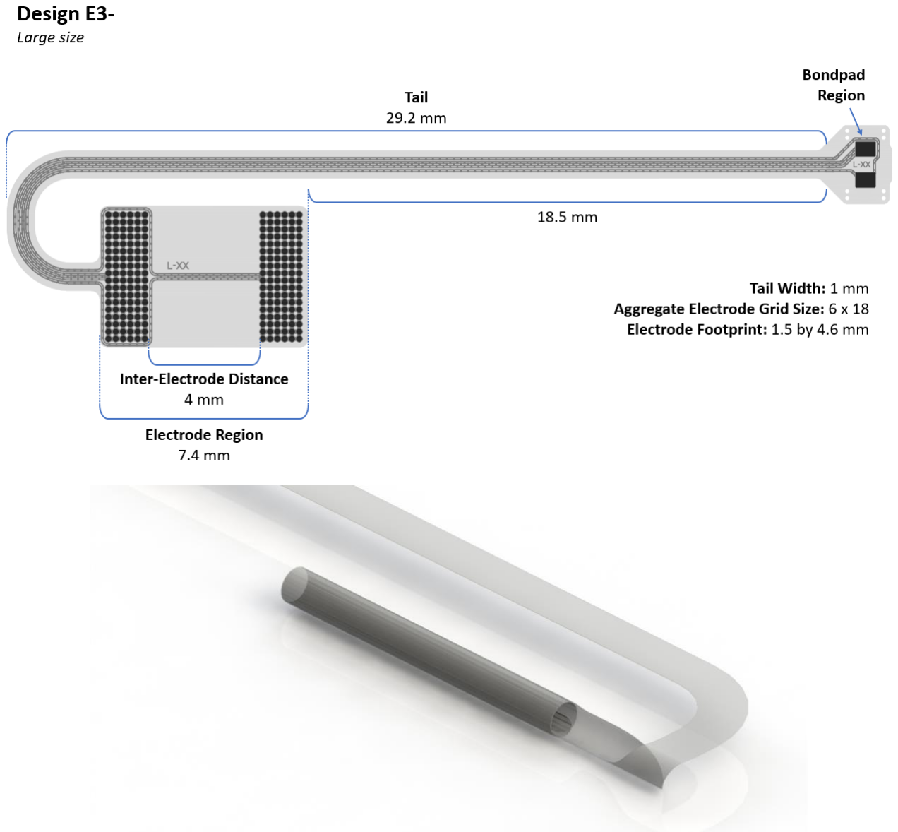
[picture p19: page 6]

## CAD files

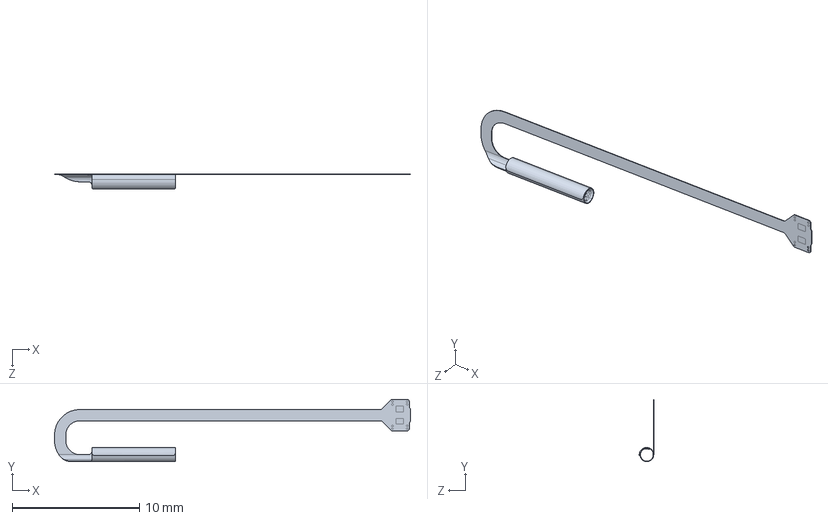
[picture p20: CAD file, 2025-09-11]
SLDPRT Files/FullLarge_Parylene.SLDPRT
28.0 x 4.90 x 1.15 mm

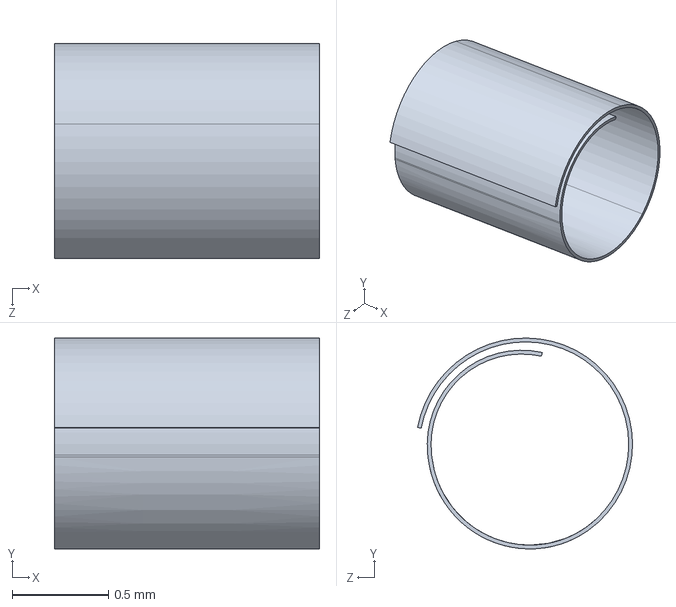
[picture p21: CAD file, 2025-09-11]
STEP Files/FullLarge_Electrode2.STEP
1.37 x 1.09 x 1.11 mm

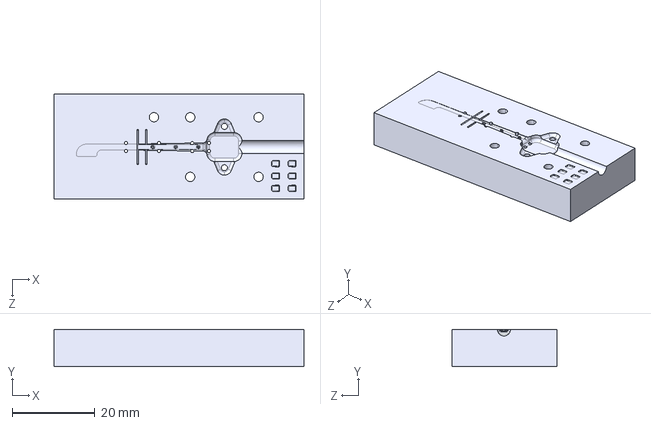
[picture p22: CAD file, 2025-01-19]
Overmold STEP and Solidworks Models (Rev 1)/OvermoldBase_v1.STEP
60.5 x 9.00 x 25.4 mm

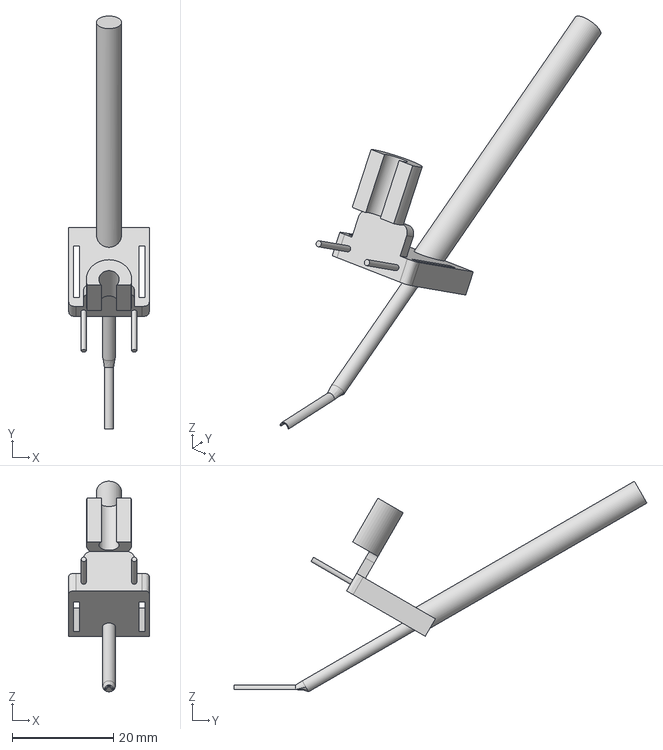
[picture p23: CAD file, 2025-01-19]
Placement tool/Placement tool.step
16.0 x 81.8 x 41.7 mm

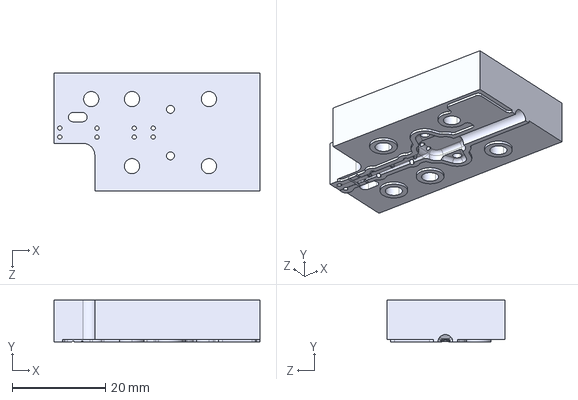
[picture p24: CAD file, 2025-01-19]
Overmold STEP and Solidworks Models (Rev 1)/OvermoldTop_v1.STEP
44.3 x 9.00 x 25.4 mm

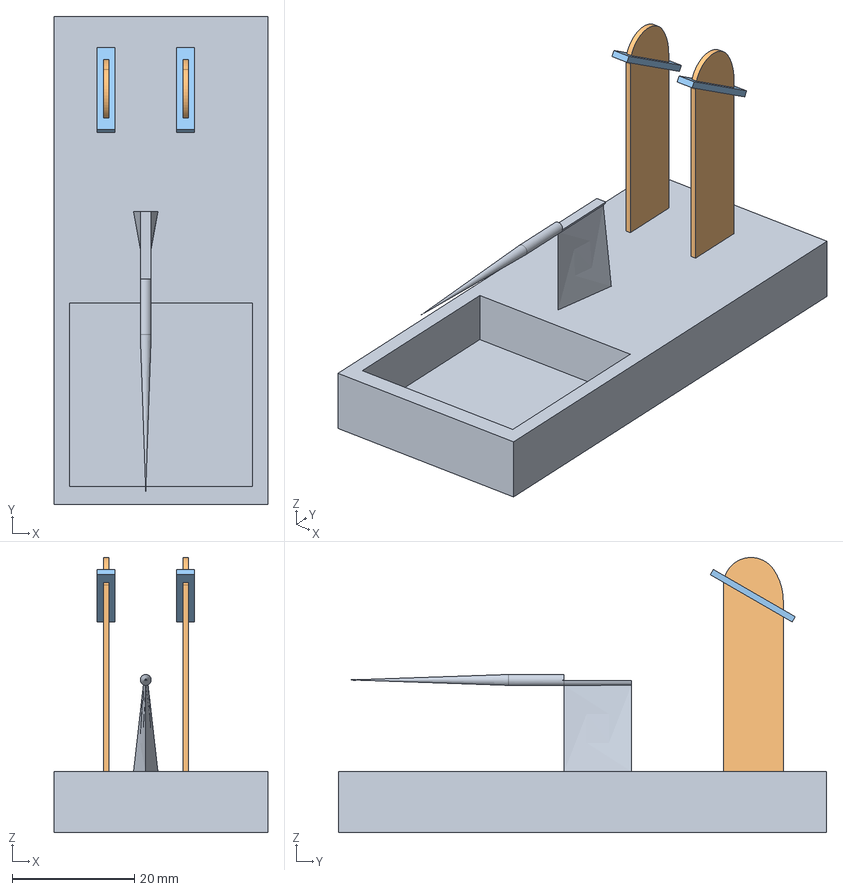
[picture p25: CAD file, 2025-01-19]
Placement tool/Placement tool-expander tool.step
35.0 x 80.0 x 45.1 mm

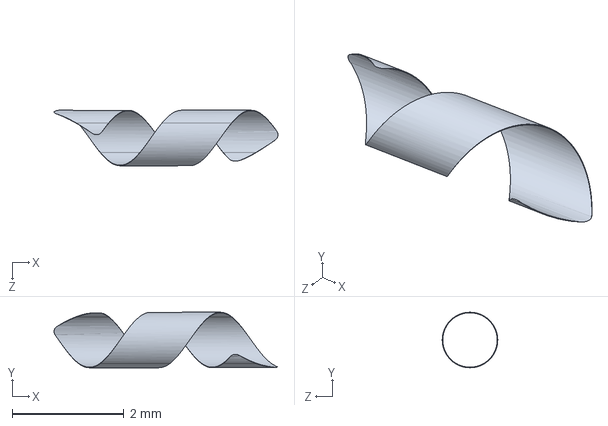
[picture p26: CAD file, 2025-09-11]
STEP Files/HelicalLarge_Electrode2.STEP
4.01 x 0.995 x 0.994 mm

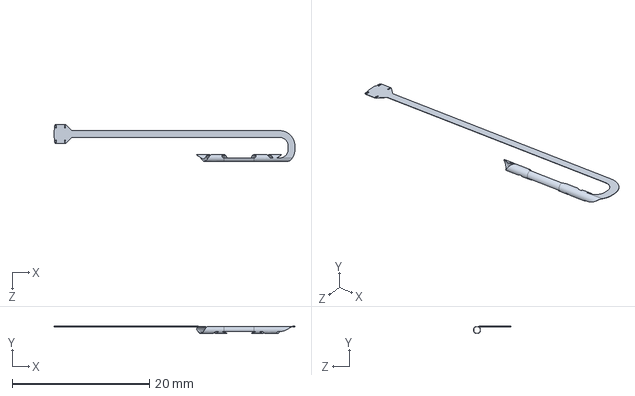
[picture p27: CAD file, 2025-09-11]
SLDPRT Files/HelicalLarge_Parylene.SLDPRT
35.2 x 1.05 x 5.42 mm

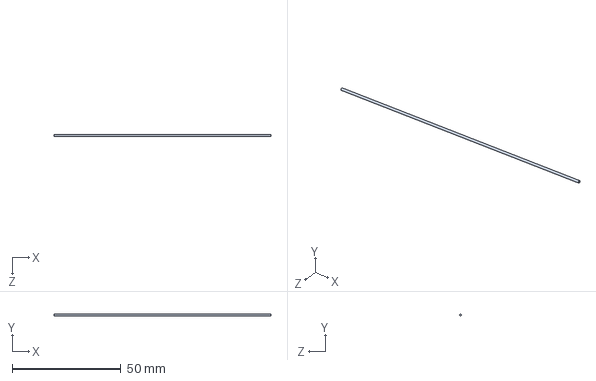
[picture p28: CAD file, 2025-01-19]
SLDPRT Files/Nerve.SLDPRT
100.0 x 0.9 x 0.9 mm

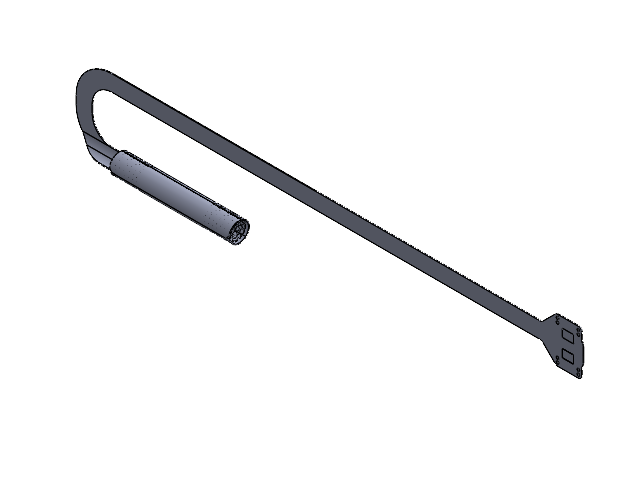
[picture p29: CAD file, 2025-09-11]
SLDPRT Files/FullLarge_Assem.SLDASM
FullCuff_Electrode1
FullCuff_Electrode2
FullCuff_Parylene

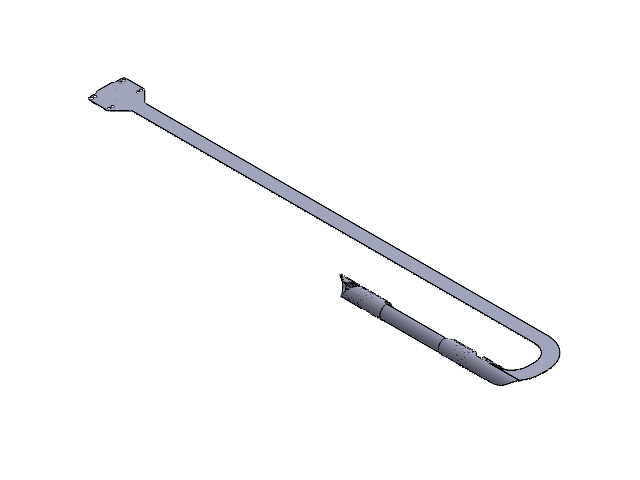
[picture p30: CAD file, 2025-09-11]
SLDPRT Files/HelicalLargeAssem.SLDASM
HelicalLarge_Parylene
HelicalLarge_Electrode1
HelicalLarge_Electrode2

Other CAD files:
STEP Files/FullLarge_Electrode1.STEP
STEP Files/HelicalLarge_Electrode1.STEP
Placement tool/Placement tool-expander tool.f3d
Placement tool/Placement tool.f3d
SLDPRT Files/FullLarge_Electrode1.SLDPRT
SLDPRT Files/FullLarge_Electrode2.SLDPRT
SLDPRT Files/HelicalLarge_Electrode1.SLDPRT
SLDPRT Files/HelicalLarge_Electrode2.SLDPRT

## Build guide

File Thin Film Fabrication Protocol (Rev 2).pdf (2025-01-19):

# NEST 4 – Thin Film Fabrication Protocol

Revision 2 (13 June 2024)

## 1 DEPOSIT BASE PARYLENE C

1.1 DRYBAKE
Note: this step should be performed immediately before Parylene deposition (step 1.2)
Materials: | 4” prime silicon wafer(s) Note: double-side polished wafers are recommended to reduce bubbles/weak adhesion of Parylene to the backside of the wafer
Equipment: | Oven or hot plate
1. Bake wafers at 110 °C in an oven at atmosphere for at least 30 minutes (overnight ok), or on a hot plate for >5 minutes

1.2 DEPOSIT PARYLENE C
Note: this step should be performed immediately after drybake (step 1.1)
Materials: | Parylene dimer
Equipment: | Parylene PVD
1. Label backside of each wafer using a permanent marker with the wafer number, date, and which shelf it will be loaded on
2. Deposit ~5 µm of Parylene C on the desired number of wafers
a. 13-14 g of dimer is typical for a batch of 12 wafers, but amount should be verified by
| comparing to past Parylene runs and adjusted as needed
b. 12 wafers per batch is recommended

1.3 ANNEAL BASE PARYLENE
Equipment: Vacuum oven with N2
1. Place wafers in a vacuum oven and evacuate the chamber to 70 cmHg or greater vacuum
2. Close vacuum valve and purge chamber with N2 to 20-30 cmHg
3. Close N2 valve and re-evacuate chamber to 70 cmHg or greater
4. Repeat steps 2 and 3 twice (three total N2 purges)
5. Bake wafers at 150 °C under full vacuum (70 cmHg or greater) for 4 hours

## 2 DEPOSIT AND PATTERN METAL

2.1 DRYBAKE
Note: this step should be performed immediately before photoresist deposition (step 2.2)

Note: this step can be skipped if the wafer anneal (step 1.3) is performed immediately prior to photoresist deposition (step 2.2)

Note: this step is critical for adhesion of small photoresist features (e.g. long, narrow traces)

Equipment: Vacuum oven with N2

1. Bake wafers at 60 °C in an oven under light vacuum (35-40 cmHg) and N2 flow (15-20 sccm) for >15 minutes

2.2 DEPOSIT PHOTORESIST
Note: this step should be performed immediately after anneal (step 1.3) or drybake (step 2.1)
Materials: | 5214 photoresist
Equipment: | Spin coater
Hot plate
1. Degas photoresist for 1 hour prior to spinning (open bottle and set it in the hood with the lights off)
2. Coat 2 dummy wafers in spin coater prior to coating real wafers
Note: this step saturates the machine with photoresist and changes the atmosphere in the spinner, leading to more consistent photoresist thicknesses between wafers

Note: the remaining steps (2.2.3 through 2.2.6) are performed one wafer at a time; repeat the following procedure once for each wafer

3. Blow wafer with N2 to remove any particles on the surface
4. Spin photoresist to ~1-2 µm thickness using the following recipe:
7 s, 500 RPM, accl 8 | spreads out PR puddle
45 s, 2000 RPM, accl 8 | defines desired thickness
Note: If photoresist is not within the range of 1-2 µm, the speed must be re-calibrated; photoresist thickness can be measured after development (step 2.4) is complete
5. Soft bake at 90 °C for 70 seconds
6. If photoresist is not applied correctly (e.g. if not enough photoresist is used to cover the entire wafer or a particle is stuck on the surface), remove the photoresist using the procedure in appendix C and return to step 2.1

2.3 EXPOSE PHOTORESIST
Equipment: Mask aligner
Metal mask

Hot plate
Plastic tray
1. Load metal mask into the mask aligner

Note: all steps (2.3.2 through 2.3.7) are performed one wafer at a time; repeat the following procedure once for each wafer

2. Load wafer into the mask aligner and center the mask pattern on the wafer
3. Expose wafer through metal mask in hard contact mode at 36.75 mJ/cm²
a. 15 mW/cm²
x 2.5 s recommended
b. Other lamp settings and timing can be used as long as the exposure dose remains the same (e.g. 12.5 mW/cm²

x 2.9 s = 36.75 mJ/cm²
)
4. Bake at 110 °C for 45 seconds (image reversal bake)
5. Rest wafer for >3 minutes to cool down
6. Flood expose wafer (expose with no mask) at 225 mJ/cm²
a. 15 mW/cm²
x 15 s recommended
b. Other lamp settings and timing can be used as long as the exposure dose remains the same (e.g. 12.5 mW/cm²

x 18 s = 225 mJ/cm²
)
7. Place wafer immediately into DI water bath after flood exposure for at least 2 minutes to prevent overheating

2.4 DEVELOP PHOTORESIST
Materials: | 340 developer
Equipment: | Plastic trays

Note: all steps (2.4.1 through 2.4.5) are performed one wafer at a time; repeat the following procedure once for each wafer

1. Develop wafer in developer bath (1:4 ratio of 340 developer to DI water) for 17 seconds with mild agitation
a. Development time may need to be adjusted based on age of photoresist and developer
| and environmental conditions, but should be within the range of 16-19 seconds
2. After development, move wafer quickly to a water bath, then flush 3x with DI water
3. Blow dry with N2
4. Inspect developed features under microscope and develop for additional time if needed
5. If photoresist is not patterned correctly (e.g. if the exposure dose is not correct, if it has been overdeveloped, or it has been scratched), remove the photoresist using the procedure in appendix C and return to step 2.1

2.5 DESCUM WAFER
Note: this step should be performed immediately before metal deposition (step 2.6)

Equipment: RIE or Asher

1. Descum (clean) wafers in the RIE or Asher using the following recipe: 100 mT, 100 W, 50 sccm O2, 5 minutes

2.6 DEPOSIT METAL
Note: this step should be performed immediately after descum (step 2.5)
Materials: | Titanium Platinum
Equipment: | E-beam evaporator
1. Deposit the metal stackup (20 nm Ti (adhesion layer) + 25 nm Pt (prevents Ti/Au interaction) + 150 nm Au + 25 nm Pt) at 1.5-2 Å/s
a. Wait 30 minutes between different types of metal to allow crucible to cool down
b. Pause for 30 minutes after each 50 nm of of gold (i.e. deposit in three 50 nm runs with
| 30 minute pauses between each run)

2.7 PATTERN METAL VIA LIFTOFF
Materials: | NMP rinse IPA Foam swab (optional)
Equipment: | Hot plate Glass dishes designated for liftoff Sonicating bath Stereoscope

Note: all steps (2.7.1 through 2.7.16) are performed one wafer at a time; repeat the following procedure once for each wafer

1. Soak wafer in 60 °C NMP rinse for 10-20 minutes with periodic mild agitation until metal begins to visibly liftoff of wafer; the wafer should be immersed just under the NMP rinse level
2. Flush the surface of the wafer with NMP from a squeeze bottle under different angles to start lifting off the metal
3. When liftoff starts, move the NMP bath out of the hotplate and keep the wafer soaking at room temperature
4. Every 10-20 minutes, flush NMP on the surface of the wafer at different angles
5. Repeat step 2.7.4 until most of the metal is lifted off
6. Transfer the wafer on a new NMP bath
a. Do not allow wafer to dry, as this will cause lifted-off metal in suspension to
| permanently stick to the wafer surface
7. Hold the NMP bath (with the wafer inside) above the sonicating bath and intermittently touch the water surface for intermittent sonication until the remaining metal appears to fully lift off
8. While in the NMP bath, inspect under a stereoscope to verify that all metal has been removed, taking special care to inspect the electrode area
9. Repeat step 2.7.7-2.7.8 if necessary

10. Once liftoff appears to be complete, move the wafer to a new NMP bath for >5 minutes
a. Do not allow wafer to dry, as this will cause lifted-off metal in suspension to permanently stick to the wafer surface
11. Lift wafer out of the room temperature NMP bath, rinse with NMP in a squeeze bottle, and move to an IPA bath for >5 minutes
a. Do not allow wafer to dry, as this will cause lifted-off metal to permanently stick to the wafer surface
12. Inspect the wafer for any remaining metal while submerged in IPA under a stereoscope
a. If any undesired metal remains (metal that has not yet been lifted off or metal flakes sitting on the surface), move wafer back to the NMP bath and repeat process from step 2.7.7
b. If any stubborn metal remains after repeating sonication, a foam swab can be used to gently dislodge metal from the wafer surface
13. Lift wafer out of the IPA bath, rinse with IPA in a squeeze bottle, and move to a DI water bath for >3 minutes
a. Do not allow wafer to dry, as this will cause lifted-off metal to permanently stick to the wafer surface
14. Re-inspect the wafer for any remaining metal while submerged in water under the stereoscope
a. If any undesired metal remains (metal that has not yet been lifted off or metal flakes sitting on the surface), move wafer back to the NMP bath and repeat process from step 2.7.7
15. Rinse wafer with DI water 3 times, and blow dry with N2
16. Inspect metal features under microscope and return to step 2.7.7 if any metal or photoresist remains

## 3 DEPOSIT TOP PARYLENE C

3.1 DESCUM WAFER
Equipment: RIE or Asher
1. Descum (clean) wafers in the RIE or Asher using the following recipe: 100 mT, 100 W, 50 sccm O2, 60 seconds

3.2 SILANIZATION
Note: this step should be performed within 12 hours of Parylene deposition (step 3.3)
Materials: | A-174 Silane
Equipment: | Glass dishes designated for A-174 Aluminum foil
1. Prepare a mixture of 900 mL DI water, 900 mL isopropanol, and 9 mL A-174 silane in a large glass beaker a. This volume is used for batches of 12 wafers; smaller quantities using the same ratio can be used for smaller batches
2. Cover the beaker with aluminum foil and let sit for at least 2.5 hours, but no more than 24 hours
3. Transfer the A-174 mixture into a crystalizing dish
4. Soak wafers face up in the A-174 mixture for 30 minutes
5. Remove the wafers and place on tex-wipes in the fume hood face up and air dry for 30 minutes
6. Rinse the wafers thoroughly with IPA for 30 minutes
7. Blow dry with N2

3.3 DEPOSIT PARYLENE C
Note: this step should be performed within 12 hours after silanization (3.2)
Materials: | Parylene dimer
Equipment: | Parylene PVD
1. Label backside of each wafer using a permanent marker with the wafer number, date, and which shelf it will be loaded on
2. Deposit ~7 µm of Parylene C on the desired number of wafers
a. 19-20 g of dimer is typical for a batch of 12 wafers, but amount should be verified by
| comparing to past Parylene runs and adjusted as needed
b. 12 wafers per batch is recommended

3.4 ANNEAL FULL WAFER
Equipment: Vacuum oven with N2
1. Place wafers in a vacuum oven and evacuate the chamber to 70 cmHg or greater vacuum
2. Close vacuum valve and purge chamber with N2 to 20-30 cmHg
3. Close N2 valve and re-evacuate chamber to 70 cmHg or greater
4. Repeat steps 2 and 3 twice (three total N2 purges)
5. Bake wafers at 150 °C under full vacuum (70 cmHg or greater) for 4 hours

## 4 PATTERN PARYLENE (STEP 1 – ELECTRODE AND BONDPAD OPENINGS)

4.1 DRYBAKE
Note: this step should be performed immediately before photoresist deposition (step 4.2)

Note: this step can be skipped if the wafer anneal (step 3.4) is performed immediately prior to photoresist deposition (step 4.2)

Equipment: Vacuum oven with N2

1. Bake wafers at 60 °C in an oven under light vacuum (35-40 cmHg) and N2 flow (15-20 sccm) for >15 minutes

4.2 DEPOSIT PHOTORESIST
Note: this step should be performed immediately after anneal (step 3.4) or drybake (step 4.1)

Materials: P4620 photoresist
Edge bead removal solvent

Equipment: Spin coater
Hot plate
1. Degas photoresist for >1 hour prior to spinning (open bottle and set it in the hood with the lights off)
2. Coat 2 dummy wafers in spin coater prior to coating real wafers
Note: this step saturates the machine with photoresist and changes the atmosphere in the spinner, leading to more consistent photoresist thicknesses between wafers

Note: the remaining steps (4.2.3 through 4.2.8) are performed one wafer at a time; repeat the following procedure once for each wafer

3. Blow wafer with N2 to remove any particles on the surface
4. Spin photoresist to 9-12 µm thickness using the following recipe:
5 s, 500 RPM, accl 4 | spreads out PR puddle
45 s, 2000 RPM, accl 15 (see below for speeds) defines desired thickness
2 s, 4500 RPM, accl 15 | edge bead removal
Note: If photoresist is not within the range of 9-12 µm, the speed must be re-calibrated; photoresist thickness can be measured after development (step 4.4) is complete
5. Remove outer ~5 mm of photoresist using a swab and edge bead removal solvent
a. This can either be done manually or by spinning the wafer in the spinner at low speed (~750 RPM) and touching the edge with a solvent-saturated swab
6. Soft bake at 90 °C for 5 minutes
7. Let wafer sit at room temperature for >3 minutes (rehydration)
8. If photoresist is not applied correctly (e.g. if not enough photoresist is used to cover the entire wafer or a particle is stuck on the surface), remove the photoresist using the procedure in appendix C and return to step 4.1

4.3 EXPOSE PHOTORESIST
Equipment: Mask aligner
Etch mask 1
Plastic tray
1. Load metal mask into the mask aligner

Note: all steps (4.3.2 through 4.3.4) are performed one wafer at a time; repeat the following procedure once for each wafer

2. Load wafer into the mask aligner and align the metal layer to the the mask pattern
3. Expose wafer through etch mask 1 in soft contact mode at 420 mJ/cm²
a. 15 mW/cm²
x 28 s recommended b. Other lamp settings and timing can be used as long as the exposure dose remains the same (e.g. 12 mW/cm²

x 35 s = 420 mJ/cm²
)
4. Place wafer immediately into DI water bath after exposure for at least 2 minutes to prevent overheating

4.4 DEVELOP PHOTORESIST
Materials: | 340 developer
Equipment: | Plastic trays: general use (unlabeled) and designated for developer

Note: all steps (4.4.1 through 4.4.5) are performed one wafer at a time; repeat the following procedure once for each wafer

1. Develop wafer in developer bath (1:4 ratio of 340 developer to DI water) for 75 seconds with mild agitation
a. Development time will need to be adjusted based on age of photoresist and developer
| and environmental conditions
2. After development, move wafer quickly to a water bath, then flush 3x with DI water
3. Blow dry with N2
4. Inspect developed features under microscope and develop for additional time if needed
5. If photoresist is not applied correctly (e.g. if the exposure dose is not correct, if it has been overdeveloped, or it has been scratched), remove the photoresist using the procedure in appendix C and return to step 4.1

4.5 ETCH PARYLENE
1. Etch through the thickness of the top Parylene layer (down to the metal layer for any exposed metal features) on each wafer using the DRIE (procedure in appendix A)

4.6 REMOVE REMAINING PHOTORESIST
1. Strip remaining photoresist off each wafer per the procedure in appendix C

## 5 PATTERN TOP PARYLENE (STEP 2 - EDGES)

1. Repeat step 4 using etch mask 2 and etching through any remaining Parylene (thickness of the base Parylene)

## 6 RELEASE DEVICES

Equipment: Scalpel Sharp tweezers Microscope

1. To remove a single device:

a. Place a droplet of water at the device edge (near one of the handling tabs)
b. Looking through a microscope, use a scalpel to gently lift the edge of the device, allowing the water to wick between the Parylene and the wafer
c. Peel the device off the wafer using sharp tweezers, holding on to the handling tab only, allowing water to continue wicking underneath the device as its lifted off
i. Add more water as needed
2. To remove all devices on a wafer:
a. Submerge the wafer in water
b. Devices should begin to lift off on their own, or you can peel the devices off individually while submerged using sharp tweezers or a scalpel

## APPENDICES

A. PARYLENE ETCHING PROCEDURE (DRIE)
Equipment: DRIE
1. Etch wafers in the DRIE through the patterned photoresist using the procedure developed in Meng et al, 2008 [1]
2. After each step, inspect wafers for any remaining Parylene in the etched areas and continue etching as needed
3. If no photoresist remains, stop etching, remove photoresist via the procedure in appendix C, and re-pattern a new photoresist layer for the current mask pattern, starting from the drybake step
B. PARYLENE ETCHING PROCEDURE (RIE)
Equipment: RIE
1. Etch wafers in the RIE through the patterned photoresist using the following parameters:
a. 150 mT, 150 W, 50 sccm O2
b. Multiple wafers can be etched at one time (if the chamber is large enough)
c. Perform in two or more steps of 15 minutes or less, rotating the wafer(s) 90-180
| degrees with each step
2. After each step, inspect wafers for any remaining Parylene in the etched areas and continue etching as needed
a. Etch rate varies depending on equipment used and number of wafers loaded in the
| machine, but should be on the order of 0.15-0.20 µm/minute
3. If no photoresist remains, stop etching, remove photoresist via the procedure in appendix C, and re-pattern a new photoresist layer for the current mask pattern, starting from the drybake step
C. PHOTORESIST STRIPPING PROCEDURE
Materials: | Acetone IPA
Equipment: | Plastic trays

1. Soak wafer in an acetone bath for 30-60 seconds with mild agitation to remove the majority of photoresist
2. Move wafer to a second acetone bath and soak for >3 minutes with periodic mild agitation
3. Move wafer to an IPA bath and soak for >3 minutes with periodic mild agitation
4. Move mask to a water bath and soak for >1 minutes with periodic mild agitation
a. Watch out for devices lifting off of the wafer at this stage, and skip the next step if it will result in loss of devices
5. Rinse gently with water, blow dry with N2
D. PROCESS FLOW DIAGRAM

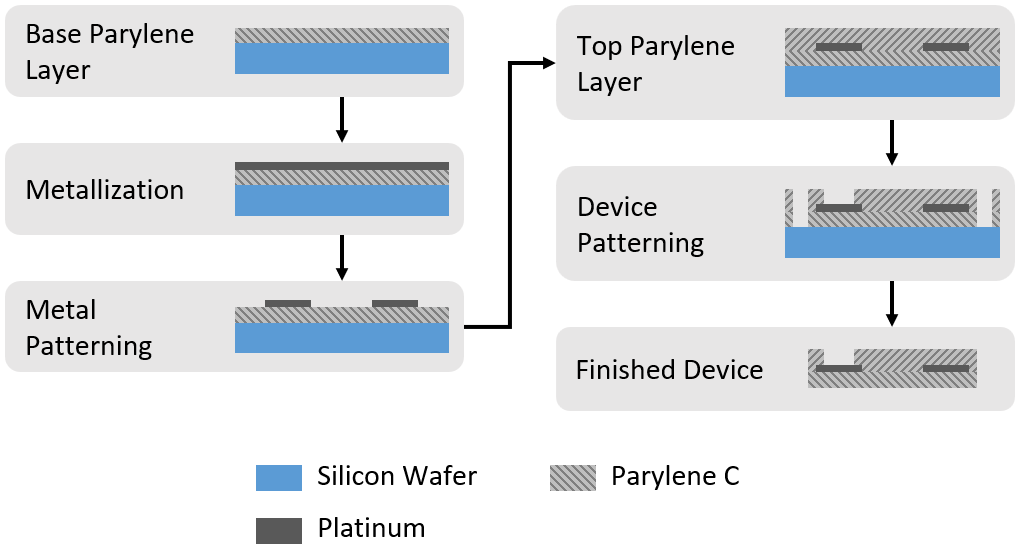
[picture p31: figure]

E. MATERIAL SOURCES
Note: Standard materials (e.g. acetone, DI water, cleanroom wipes, etc.) are not listed
Material | Supplier
CR-7 chrome etchant | Transene, Danvers, MA
Parylene dimer | Specialty Coating Systems, Indianapolis, IN
P4620 photoresist | AZ Electronic Materials, Branchburg, NJ
5214 photoresist | AZ Electronic Materials, Branchburg, NJ
340 developer | AZ Electronic Materials, Branchburg, NJ
Edge Bead Removal (EBR) solvent | AZ Electronic Materials, Branchburg, NJ
NMP Rinse | AZ Electronic Materials, Branchburg, NJ
Titanium | Provided by USC cleanroom
Platinum | Provided by USC cleanroom
Gold | Provided by USC cleanroom
Nanostrip 2X | CMC Materials, Santa Ana, CA

F. EQUIPMENT MODELS
Note: Standard equipment (e.g. tweezers, microscopes, N2 gun, scale, etc.) are not listed
Equipment | Model # | Supplier
Vacuum oven with N2 | TVO-2 | Cascade Tek Inc., Longmont, CO
| VO914A | Lindberg/Blue M, New Columbia, PA
Profilometer | DektakXT | Bruker, Billerica, MA
Spin coater | WS-400B-6NPP Lite | Laurell Technologies, North Wales, PA
Hot plate | PMC 730 Dataplate | Barnstead/Thermolyne, Dubuque, IA
| 1000-1 | Electronic Micro Systems, Sutton Coldfield, UK
Sonicating bath | 3510 | Branson Ultrasonics, Danbury, CT
DRIE | Plasmalab 100 | Oxford Instruments, Bristol, UK
RIE | PlasmaPro 80 | Oxford Instruments, Bristol, UK
| Series 85 | Technics, Pleasanton, CA
Asher | CV200RFS | Yield Engineering Systems, Fremont, CA
Mask aligner | Model 200 | OAI, San Jose, CA
E-beam evaporator | Mark 40 | CHA Industries, Livermore, CA
| PRO Line PVD 75 | Kurt J. Lesker, Jefferson Hills, PA
Parylene PVD | PDS 2010 Labcoter | Specialty Coating Systems, Indianapolis, IN
G. REFERENCES
1. E. Meng, P. Y. Li, and Y.-C. Tai, “Plasma removal of Parylene C,” J. Micromechanics Microengineering, vol. 18, no. 4, p. 045004, 2008, doi: 10.1088/0960-1317/18/4/045004.

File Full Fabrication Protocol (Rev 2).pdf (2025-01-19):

# NEST 4 – Full Fabrication Protocol

Revision 2 (7 June 2024)

## 1 THIN FILM FABRICATION

1. Follow the procedure in the thin film fabrication protocol to produce released thin film Parylene electrodes (in their flat configuration)

## 2 INSPECT AND TEST

2.1 VISUAL INSPECTION
Equipment: Stereoscope Microscope with at least 10x magnification
1. Using the stereoscope, inspect the device for any large mechanical failures, such as:
a. Folded Parylene
b. Torn Parylene
c. Metal delamination
d. Incorrect thermoformed shape
2. Using 5x and 10x magnification (or higher), inspect the device for microscopic mechanical failures, such as:
a. Parylene cracks
b. Torn Parylene
c. Metal cracks
d. Metal delamination
3. If any defects are found in functional device areas, the device should not be used
Note: defects such as Parylene cracks only in the tabs or metal cracks only in the label which do not impact the electrodes, traces, or bondpads are ok

2.2 SHORTING AND IMPEDANCE CHECK (OPTIONAL)
Equipment: | LCR Meter Stereoscope
Materials: | Platinum wire electrode Small wire or probe (2) 1x PBS
1. Set the LCR meter to measure impedance using a 10 kHz, 20 mV signal
2. Place the mounted device under a stereoscope with the bondpads in view
3. Using two small wires or probes, probe the two bondpads to check for electrical shorting between the two electrodes a. If impedance magnitude is less than 100 kΩ or impedance phase is greater than (i.e. closer to zero than) -65°, the electrodes are shorted and the device should not be used
4. Drop PBS on the device to cover the electrodes only
5. Connect the platinum wire electrode to one of the LCR probes and place the platinum wire in contact with the PBS droplet
6. Probe each bondpad to test channel impedance
a. If impedance magnitude is greater than 100 kΩ or impedance phase is less than (i.e. farther from zero than) -65°, the trace is broken and the device should not be used
7. Remove all probes and wires, gently rinse the device with DI water, and allow to air dry

## 3 LEAD ATTACH – WITH CONDUCTIVE EPOXY

Note: For lead attach, either step 3 OR step Error! Reference source not found. can be used.

3.1 CONNECT LEADS TO PARYLENE CABLE
Materials: | Desired lead wire, cut to length (100-110 cm for lifetime test parts) EpoTEK MED-H20E epoxy
Equipment: | Oven
1. Mix Epo-TEK H20E silver epoxy per manufacturer recommendation
2. If lead wire is insulated, strip 1 mm of insulation off one end of each wire and 3-8 mm of insulation of the other end of each wire
3. Align one lead wire (1 mm exposed end) to each bondpad manually or using a vacuum tool and hold in place using Kapton tape
a. Kapton tape should not cover or interfere with the bondpad or the length of the lead
| wire which passes over the bondpad
b. Ensure the wire is flat against the bondpad to allow for a stronger connection
c. Add enough tape to the free end of the wire to prevent any movement during further
| processing steps
4. Using a toothpick, needle, or scrap wire, pick up a small volume of Epo-TEK H20E epoxy and dab it over each exposed wire and bondpad, ensuring the two wires/bondpads to not short to each other
a. If possible, prevent contact with the Teflon sheet – epoxy can be separated from the
| Teflon sheet if it comes in contact but it is difficult to do
5. Cure epoxy for 3-4 hours at 85 °C
6. Remove device from oven

3.2 INSULATE CONNECTIONS
Materials: | EpoTEK MED-301 epoxy
Equipment: | Teflon film Oven
1. Use IPA to release and remove any Kapton tape applied in the previous step

2. Mix a small volume of EpoTEK 301 epoxy
3. Using a toothpick or needle, pick up a small volume of epoxy and dab it over each exposed wire/bondpad/silver epoxy connection, ensuring all conductive areas are covered
4. Cure the epoxy at 65 °C for at least 1 hour
5. Repeat process once to apply second coat of epoxy
a. Note: same mixed batch of epoxy can be used if it is stored in the refrigerator or freezer for less than 4 hours
6. Repeat process if any areas exposed areas remain or a stronger connection is desired

## 4 INSPECT AND TEST

4.1 VISUAL INSPECTION
Equipment: Stereoscope Microscope with at least 10x magnification
1. Using the stereoscope, inspect the device for any large mechanical failures, such as:
a. Folded Parylene
b. Torn Parylene
c. Metal delamination
d. Damaged silicone
e. Incorrect molding
2. If any defects are found in functional device areas, the device should not be used
Note: defects such as Parylene cracks only in the tabs or metal cracks only in the label which do not impact the electrodes, traces, or bondpads are ok

4.2 SHORTING AND IMPEDANCE CHECK
Equipment: | LCR Meter Stereoscope
Materials: | Platinum wire electrode Small wire or probe (2) PBS
1. Set the LCR meter to measure impedance using a 10 kHz, 20 mV signal
2. Place the mounted device under a stereoscope with the bondpads in view
3. Using two small wires or probes, probe the two bondpads to check for electrical shorting between the two electrodes
a. If impedance magnitude is less than 100 kΩ or impedance phase is greater than (i.e.
| closer to zero than) -65°, the electrodes are shorted and the device should not be used
4. If performing step 4.3 (CV), the remaining steps can be skipped
5. Drop PBS on the device to cover the electrodes only
6. Connect the platinum wire electrode to one of the LCR probes and place the platinum wire in contact with the PBS droplet
7. Probe each bondpad to test channel impedance a. If impedance magnitude is greater than 100 kΩ or impedance phase is less than (i.e. farther from zero than) -65°, the trace is broken and the device should not be used
8. Remove all probes and wires, gently rinse the device with DI water, and allow to air dry

4.3 CYCLIC VOLTAMMETRY (H2SO4) (OPTIONAL)
Equipment: | Potentiostat with faraday cage
Materials: | Ag/AgCl reference electrode Platinum counter electrode 0.05 M H2SO4
1. Submerge the electrode end of the cuff in IPA for 1-5 minutes, using a wire or other clamp to hold the cuff underneath the surface
2. Remove the device from the IPA and submerge the electrode end of the cuff in DI water for at least 10 minutes, using a wire or other clamp to hold the cuff underneath the surface
3. Prepare a 50 mL beaker with ~25 mL of 0.05 M H2SO4 and purge with N2
a. Purge for at least 5 minutes prior to beginning CV
b. Continue purging during testing if possible
4. Remove the device from the DI water and submerge the electrode end of the cuff in the H2SO4, using a wire or other clamp to hold the cuff underneath the surface; do submerge deep enough such that the connection point to the lead is submerged
5. Rinse the Ag/AgCl reference electrode and platinum counter electrode in DI water, then place them in the H2SO4 beaker, taking care not to touch the Parylene cuff
6. Connect the reference electrode, counter electrode, and one lead wire (working electrode) to the potentiostat in a 3-electrode setup
7. Perform CV for 30 cycles from -0.2 to 1.2 V with 250 mV/s scan rate
a. Calculate the electroactive surface area and cathodic charge storage capacity using the
| equations in appendix C and appendix E
8. Move the working electrode connection to the other lead wire
9. Repeat step Error! Reference source not found. for the second electrode
10. Turn off N2 purging
11. Remove the reference and counter electrodes from the beaker and rinse with DI water
12. Remove the fixtured device from the beaker and re-submerge in DI water for at least 5 minutes
13. If not proceeding to the next test within the day, remove the device from the DI water and allow to air dry

## 5 THERMOFORM

5.1 FIXTURE
Materials: Thermoforming mandrel * Glass slides Binder clips Oven safe tray

Teflon film (0.001”/25 µm thick or thinner) Kapton tape (0.0025”/64 µm thick or thinner)

* 1.5-2 inch long dispensing tip of the desired diameter

* Mandrel (dispensing tip) size is 0.1-0.2 mm smaller than the desired inner diameter of the cuff:

For 0.5 mm cuffs: 0.4 mm mandrel (27 gauge tip)
For 0.7 mm cuffs: 0.5 mm mandrel (25 gauge tip)

Note: a video of the thermoforming fixturing process is provided to accompany the following procedure

1. Prepare one fixture per part to be thermoformed using the following procedure.
a. Cut a piece of Teflon film to 2 cm x 4 cm
b. Cut a piece of Kapton tape to 2 cm x 1 mm
c. Tape one of the 2 cm sides of the Teflon film along the length of the mandrel using the Kapton tape
d. Clip the free end of the Teflon film to the short end of a glass slide so that the film and mandrel are lying on the glass with the tape side down
a. Place the assembly underneath a microscope with the clip side towards you, prop the free end of the glass slide up 3-5 mm, and push the slide against a heavy block (so that you can push against it without moving the fixture in later steps); see Figure 5-1 for full fixture setup

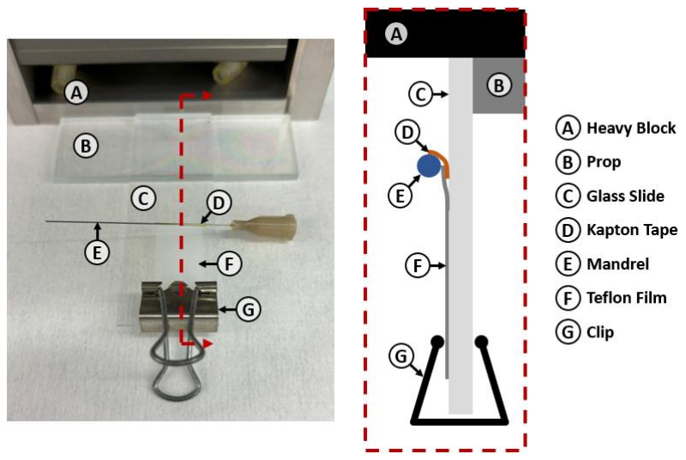
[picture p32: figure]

Figure 5-1: Cuff thermoforming fixture setup (cross section, shown in red dotted box, is not to scale).

2. Lift the mandrel away from the glass slide (while still clipped in place), lay the Parylene cable beneath the Teflon film (with bondpad region to the left and electrodes facing up), and lower the Teflon film on top of the cable
3. Slide the electrodes over the Teflon film and align them near the mandrel (see Figure 5-2)

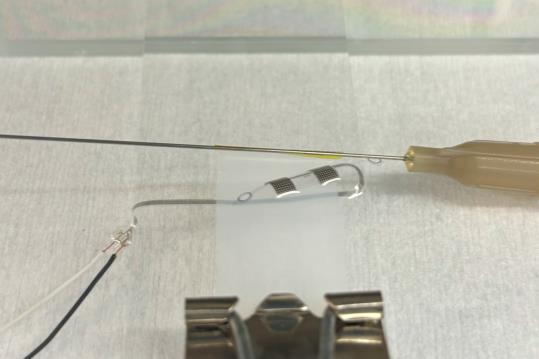
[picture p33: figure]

Figure 5-2: Initial placement of the device on the thermoforming fixture.

4. Place a small droplet of IPA underneath the electrode region of the Parylene device and touch the Parylene down to the Teflon film, allowing it to wick between the Parylene and Teflon and hold it in place
5. Align the Parylene electrode such that the center bridge is parallel to the mandrel, the top edge of the electrodes is touching the mandrel, and the tail is extended over the edge of the Teflon film (see Figure 5-3)

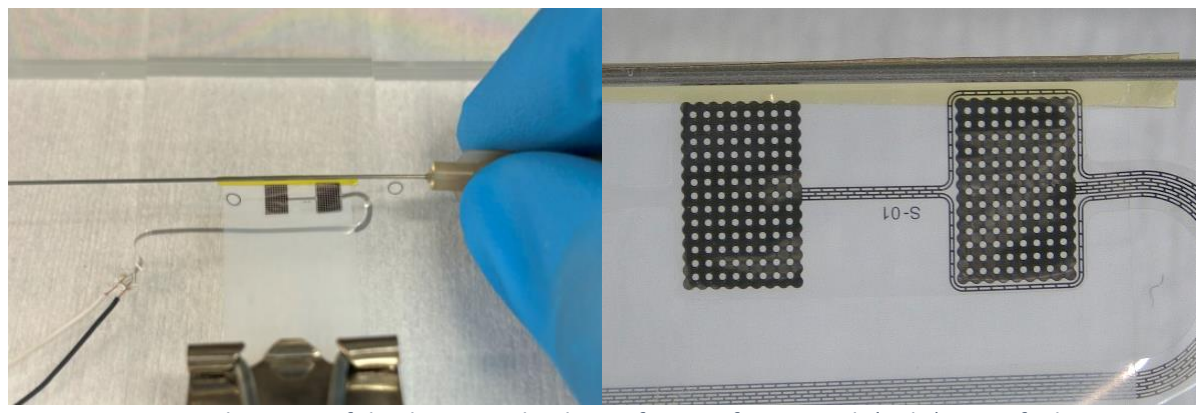
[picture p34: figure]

Figure 5-3: Alignment of the device on the thermoforming fixture, with (right) magnified view.

6. Hold the Teflon film tight by gently pulling the mandrel away from you and against the heavy block, then roll the mandrel towards you, rolling the Parylene electrodes around the mandrel (see Figure 5-4)

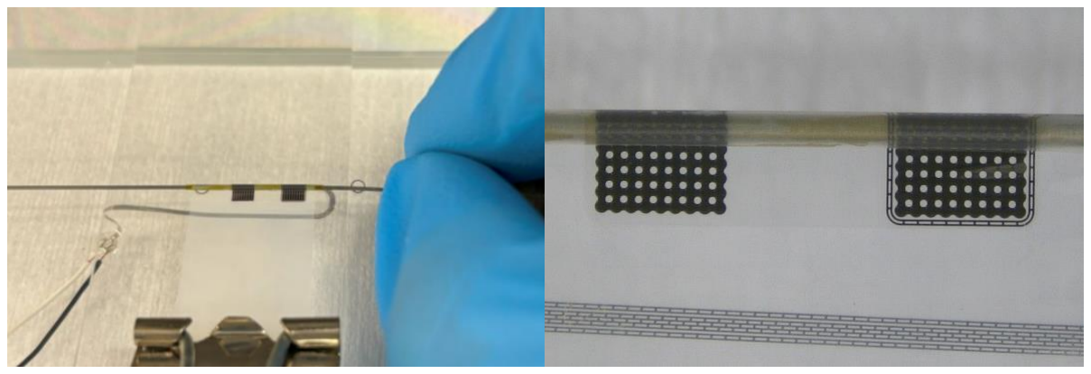
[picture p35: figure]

Figure 5-4: Device partially rolled into the thermoforming fixture, with (right) magnified view.

7. Continue rolling until the entire Parylene electrode is covered, maintaining tension on the Teflon film and watching to ensure the Parylene does not fold or kink

8. Gently lift the mandrel while maintaining tension in the Teflon film and move the Parylene cable around the back of the mandrel and on top of the Teflon film (untangling it, see Figure 5-5)

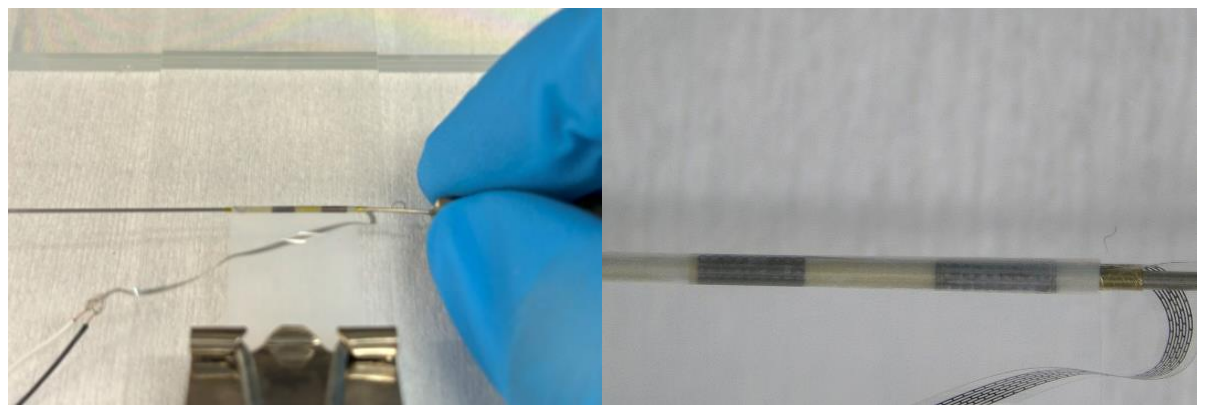
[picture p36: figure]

Figure 5-5: Device fully rolled around the thermoforming fixture, with (right) magnified view.

9. Roll the remainder of the Teflon film around the mandrel, leaving the tail unrolled, and hold film in place using two small pieces of Kapton tape
10. While maintaining tension on the film by holding the mandrel on the right side, place a clip on the left side of the mandrel, clamping it to the glass slide
11. Gently rearrange the Parylene cable with wires attached so that the wires are parallel to the long end of the glass slide and there is slack in the Parylene cable, and tape the wires down to the glass slide using Kapton tape, taking care not to tug on the Parylene cable and cause damage to the device (see Figure 5-6)

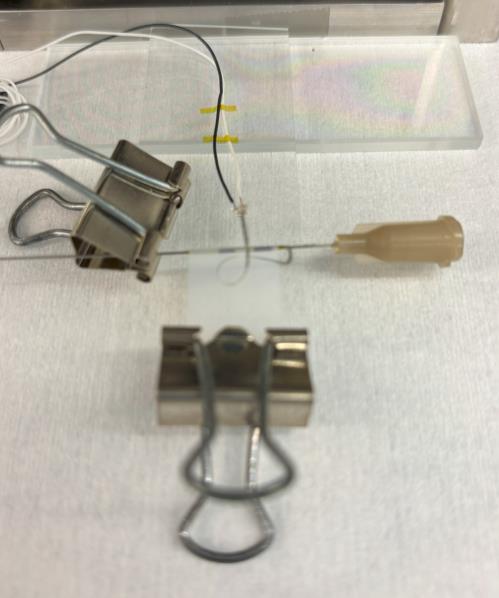
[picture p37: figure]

Figure 5-6: Device rolled around the thermoforming fixture and clamped on the left side of the mandrel, with wires taped to glass slide with some slack in the Parylene cable.

12. Add another clip on the right side of the mandrel, taking care not to clip directly on top of the Parylene cable
13. Remove the clip holding the Teflon film, and gently pull the film taut by hand to remove any slack that was introduced during the clamping process (see Figure 5-7)

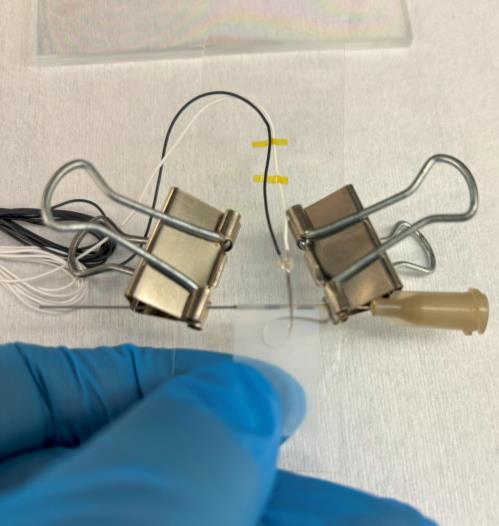
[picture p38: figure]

Figure 5-7: Fixtured device clamped on both sides of the mandrel while Teflon film is gently being pulled to remove any slack.

14. While holding the film taut, place one clip to hold the Teflon film to the glass slide as close to the rolled device as possible without causing damage, then release the film and place a second clip on the other side of the Teflon film (see Figure 5-8)

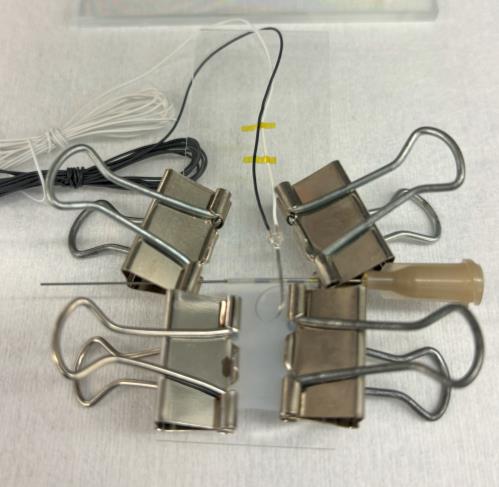
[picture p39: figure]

Figure 5-8: Fixtured device with two clamps holding the mandrel to the glass slide and two clamps holding the Teflon film to the glass slide.

### 5.2 BAKE

Equipment: Vacuum oven with N2

1. Carefully place the fixtured part (on an oven safe tray) in a vacuum oven, close, and evacuate chamber to 70 cmHg or greater vacuum
2. Purge chamber with N2 to 20-30 cmHg, then re-evacuate to 70 cmHg or greater
3. Repeat step 2 twice (three total N2 purges)
4. Bake parts (under vacuum) for 12 hours at 100 °C
5. Remove tray from oven after temperature has cooled to below 80 °C
6. Remove all clamps from the thermoforming fixture and release the device from the fixture

5.3 OVERMOLD
Equipment: | Device mold Vacuum chamber Oven Dispensing tips (19-21 gauge)
Materials: | Mold release (2% liquinox) PDMS
1. Apply a thin layer of mold release onto all inner surfaces of the device mold and blow dry
2. Mix PDMS thoroughly and degas in a vacuum chamber until no bubbles are visible
3. Fill the base of the mold with PDMS, and degas again if necessary
4. Place device into the base of the mold using the pins to ensure correct alignment
5. Fill the top of the mold with PDMS, and degas again if necessary
6. Carefully put the top of the mold in place and screw closed, using the pins to ensure correct alignment and taking care not to damage the device
7. Place the thermoformed electrode array inside a syringe dispensing tip with inner diameter equal to the thermoformed diameter of the cuff, and tape the dispensing tip to the mold
a. Note: this step prevents loosening of the thermoformed cuff at elevated temperatures
8. Bake the molded part for at least 4 hours at 65 °C
9. Remove the mold from the oven
10. Release the electrode array from the dispensing tip
11. Unscrew the screws on the mold, and carefully separate the top and bottom pieces of the mold
12. Carefully remove the device from the mold, and remove any excess PDMS (flash) from the edges of the molded part

## 6 INSPECT AND TEST

6.1 VISUAL INSPECTION
Equipment: Stereoscope Microscope with at least 10x magnification
1. Using the stereoscope, inspect the device for any large mechanical failures, such as:
a. Folded Parylene
b. Torn Parylene
c. Metal delamination
d. Damaged silicone
e. Incorrect molding
2. If any defects are found in functional device areas, the device should not be used
Note: defects such as Parylene cracks only in the tabs or metal cracks only in the label which do not impact the electrodes, traces, or bondpads are ok

6.2 SHORTING CHECK
Equipment: | LCR Meter Stereoscope
Materials: | Platinum wire electrode Small wire or probe (2) PBS
1. Set the LCR meter to measure impedance using a 10 kHz, 20 mV signal
2. Place the mounted device under a stereoscope with the bondpads in view
3. Measure the impedance between the two leads to check for electrical shorting between the two electrodes
a. If impedance magnitude is less than 100 kΩ or impedance phase is greater than (i.e.
| closer to zero than) -65°, the electrodes are shorted and the device should not be used

6.3 CYCLIC VOLTAMMETRY (H2SO4)
Equipment: | Potentiostat with faraday cage
Materials: | Ag/AgCl reference electrode Platinum counter electrode 0.05 M H2SO4
1. Submerge the electrode end of the cuff in IPA for 1-5 minutes, using a wire or other clamp to hold the cuff underneath the surface
2. Remove the device from the IPA and submerge the electrode end of the cuff in DI water for at least 10 minutes, using a wire or other clamp to hold the cuff underneath the surface
3. Prepare a 50 mL beaker with ~25 mL of 0.05 M H2SO4 and purge with N2
a. Purge for at least 5 minutes prior to beginning CV
b. Continue purging during testing if possible
4. Remove the device from the DI water and submerge the electrode end of the cuff in the H2SO4, using a wire or other clamp to hold the cuff underneath the surface; do submerge deep enough such that the connection point to the lead is submerged
5. Rinse the Ag/AgCl reference electrode and platinum counter electrode in DI water, then place them in the H2SO4 beaker, taking care not to touch the Parylene cuff
6. Connect the reference electrode, counter electrode, and one lead wire (working electrode) to the potentiostat in a 3-electrode setup
7. Perform CV for 30 cycles from -0.2 to 1.2 V with 250 mV/s scan rate
a. Calculate the electroactive surface area and cathodic charge storage capacity using the
| equations in appendix C and appendix E
8. Move the working electrode connection to the other lead wire
9. Repeat step Error! Reference source not found. for the second electrode
10. Turn off N2 purging
11. Remove the reference and counter electrodes from the beaker and rinse with DI water
12. Remove the fixtured device from the beaker and re-submerge in DI water for at least 5 minutes

13. If not proceeding to the next test within the day, remove the device from the DI water and allow to air dry

6.4 CYCLIC VOLTAMMETRY (FERRI/FERRO) (OPTIONAL)
Equipment: | Potentiostat with faraday cage
Materials: | Ag/AgCl reference electrode Platinum counter electrode 0.5 mM ferri/ferrocyanide

Note: This step is optional for more accurate measurement of electroactive surface area

Note: This step should not be performed for in vivo parts

1. If the cuff is dry, submerge the electrode end of the cuff in IPA for 1-5 minutes, using a wire or other clamp to hold the cuff underneath the surface
2. Remove the device from the IPA and submerge the electrode end of the cuff in DI water for at least 1 minute, using a wire or other clamp to hold the cuff underneath the surface
3. Prepare a 50 mL beaker with ~25 mL of 0.5 mM ferri/ferro
4. Remove the device from the DI water and submerge the electrode end of the cuff in the ferri/ferro, using a wire or other clamp to hold the cuff underneath the surface; do submerge deep enough such that the connection point to the lead is submerged
5. Rinse the Ag/AgCl reference electrode and platinum counter electrode in DI water, then place them in the ferri/ferro beaker, taking care not to touch the Parylene cuff
6. Connect the reference electrode, counter electrode, and one lead wire (working electrode) to the potentiostat in a 3-electrode setup
7. Perform CV from -0.4 to 1.0 V for 1 cycle at each of the following scan rates: 100 mV/s, 80 mV/s, 50 mV/s, and 20 mV/s
a. Calculate the electroactive surface area using the equation in appendix D
8. Move the working electrode connection to the other lead wire
9. Repeat step Error! Reference source not found. for the second electrode
10. Remove the reference and counter electrodes from the beaker and rinse with DI water
11. Remove the fixtured device from the beaker and re-submerge in DI water for at least 5 minutes
12. If not proceeding to the next test within the day, remove the device from the DI water and allow to air dry

6.5 ELECTROCHEMICAL IMPEDANCE SPECTROSCOPY (PBS)
Equipment: | Potentiostat with faraday cage
Materials: | 50 mL beaker Ag/AgCl reference electrode Platinum counter electrode PBS
1. If the cuff is dry, submerge the electrode end of the cuff in IPA for 1-5 minutes, using a wire or other clamp to hold the cuff underneath the surface

2. Remove the device from the IPA and submerge the electrode end of the cuff in DI water for at least 10 minutes, using a wire or other clamp to hold the cuff underneath the surface
3. Prepare a 50 mL beaker with ~25 mL of 1x PBS
4. Remove the device from the DI water and submerge the electrode end of the cuff in the PBS, using a wire or other clamp to hold the cuff underneath the surface; do submerge deep enough such that the connection point to the lead is submerged
5. Rinse the Ag/AgCl reference electrode and platinum counter electrode in DI water, then place them in the PBS beaker, taking care not to touch the Parylene cuff
6. Connect the reference electrode, counter electrode, and one lead wire (working electrode) to the potentiostat in a 3-electrode setup
7. Perform EIS using 25 mVrms over the range of 1 to 10⁶ Hz
a. If impedance magnitude at 1 kHz is greater than 10 kΩ or impedance phase shows uncharacteristic behavior, the electrode is open and the device should not be used
8. Move the working electrode connection to the other lead wire
9. Repeat step Error! Reference source not found. for the second electrode
10. To test the insulation integrity of the lead connection point, add more PBS to the beaker until the lead connection is submerged and repeat EIS – any significant changes in impedance and phase indicate leakage in the connection point
11. Proceed directly to CV in PBS

6.6 CYCLIC VOLTAMMETRY (PBS)
Equipment: | Potentiostat with faraday cage
Materials: | Ag/AgCl reference electrode Platinum counter electrode 1x PBS
1. If the cuff is dry, submerge the electrode end of the cuff in IPA for 1-5 minutes, using a wire or other clamp to hold the cuff underneath the surface
2. Remove the device from the IPA and submerge the electrode end of the cuff in DI water for at least 5 minutes, using a wire or other clamp to hold the cuff underneath the surface
3. Verify the reference electrode, counter electrode, and one lead wire (working electrode) are connected to the potentiostat in a 3-electrode setup
4. Perform CV for 1 cycle from -0.6 to 0.8 V with 50 mV/s scan rate
a. Calculate the electroactive surface area and cathodic charge storage capacity using the
| equations in appendix C and appendix E
5. Move the working electrode connection to the other lead wire
6. Repeat step Error! Reference source not found. for the second electrode
7. Remove the reference and counter electrodes from the beaker and rinse with DI water
8. Remove the fixtured device from the beaker and re-submerge in DI water for at least 5 minutes
9. Proceed directly to VT in PBS

6.7 VOLTAGE TRANSIENT MEASUREMENT (PBS)
Equipment: Galvanostat with faraday cage

Materials: Ag/AgCl reference electrode Platinum counter electrode 1x PBS

1. If the cuff is dry, submerge the electrode end of the cuff in IPA for 1-5 minutes, using a wire or other clamp to hold the cuff underneath the surface
2. Remove the device from the IPA and submerge the electrode end of the cuff in DI water for at least 5 minutes, using a wire or other clamp to hold the cuff underneath the surface
3. Prepare a 50 mL beaker with ~30 mL of PBS.
4. Remove the device from the DI water and submerge the electrode end of the cuff in the PBS, using a wire or other clamp to hold the cuff underneath the surface; do submerge deep enough such that the connection point to the lead is submerged.
5. Rinse the Ag/AgCl reference electrode and platinum counter electrode in DI water, then place them in the PBS beaker, taking care not to touch the Parylene cuff.
6. Connect the reference electrode, counter electrode, and one lead wire (working electrode) to the potentiostat in a 3-electrode setup
7. Stimulate one pulse with 1 mA amplitude, 500 µs pulse width, and 100 µs interpulse delay and record the resulting voltage
8. Calculate the interphase potential from the resulting voltage pulse
a. Continue pulsing until the current to reach approximately -0.6 V interphase potential is
| reached, using the following guidelines:
b. If the interphase potential is greater than -0.58 V (i.e., closer to 0 V), increase the
| current amplitude and repeat steps 7 and 8
c. If the interphase potential is smaller than -0.62 V (i.e., a larger negative value), decrease
| the current amplitude and repeat steps 7 and 8
d. Do not exceed a current amplitude of 10 mA
e. If the exact current amplitude cannot be determined, collect at least three data points
| with interphase potential greater than -0.6 V (i.e., closer to 0 V) and linearly extrapolate
9. Repeat steps 7 and 8 using a pulse width of 200 µs and interpulse delay of 40 µs to reach an interphase potential of -0.6 with the following guidelines:
a. If the interphase potential is greater than -0.58 V (i.e., closer to 0 V), increase the
| current amplitude and repeat steps 7 and 8
b. If the interphase potential is smaller than -0.62 V (i.e., a larger negative value), decrease
| the current amplitude and repeat steps 7 and 8
c. Do not exceed a current amplitude of 10 mA
d. If the exact current amplitude cannot be determined, collect at least three data points
| with interphase potential greater than -0.6 V (i.e., closer to 0 V) and linearly extrapolate
e. If there is insufficient interpulse delay for the interphase potential to be read, increase
| the interpulse delay to 80 µs
10. Move the working electrode connection to the other lead wire
11. Repeat steps 7 through 9 for the second electrode
12. Disconnect the device and rinse in DI water
13. Allow the device to air dry
14. Calculate the charge injection capacity (CIC) for each electrode using the equations in appendix F.

## 7 PACKAGE DEVICE

### 7.1 CLEAN

Materials: 3x 50 mL beaker

1. Fill one beaker with ~25 mL of IPA and two beakers with ~25 mL of DI water
2. Dunk the device into the IPA (ensuring any portion which will be implanted is submerged) and gently agitate for 60-120 seconds
3. Move the device to the first water beaker (ensuring any portion which will be implanted is submerged) and gently agitate for 60-120 seconds
4. Move the device to the second water beaker (ensuring any portion which will be implanted is submerged) and gently agitate for 60-120 seconds
5. Remove the device from the water and allow to air dry

## APPENDICES

A. MATERIAL SOURCES
Note: Standard materials (e.g. acetone, DI water, cleanroom wipes, etc.) are not listed
Material | Supplier
MED-H20E Silver Epoxy | Epo-TEK, Billerica, MA
MED-301 Epoxy | Epo-TEK, Billerica, MA
B. EQUIPMENT MODELS
Note: Standard equipment (e.g. tweezers, microscopes, N2 gun, scale, etc.) are not listed
Equipment | Model # | Supplier
Vacuum oven with N2 | TVO-2 | Cascade Tek Inc., Longmont, CO
| VO914A | Lindberg/Blue M, New Columbia, PA
Potentiostat Galvanostat | Reference 600 | Gamry Instruments Inc., Warminster, PA

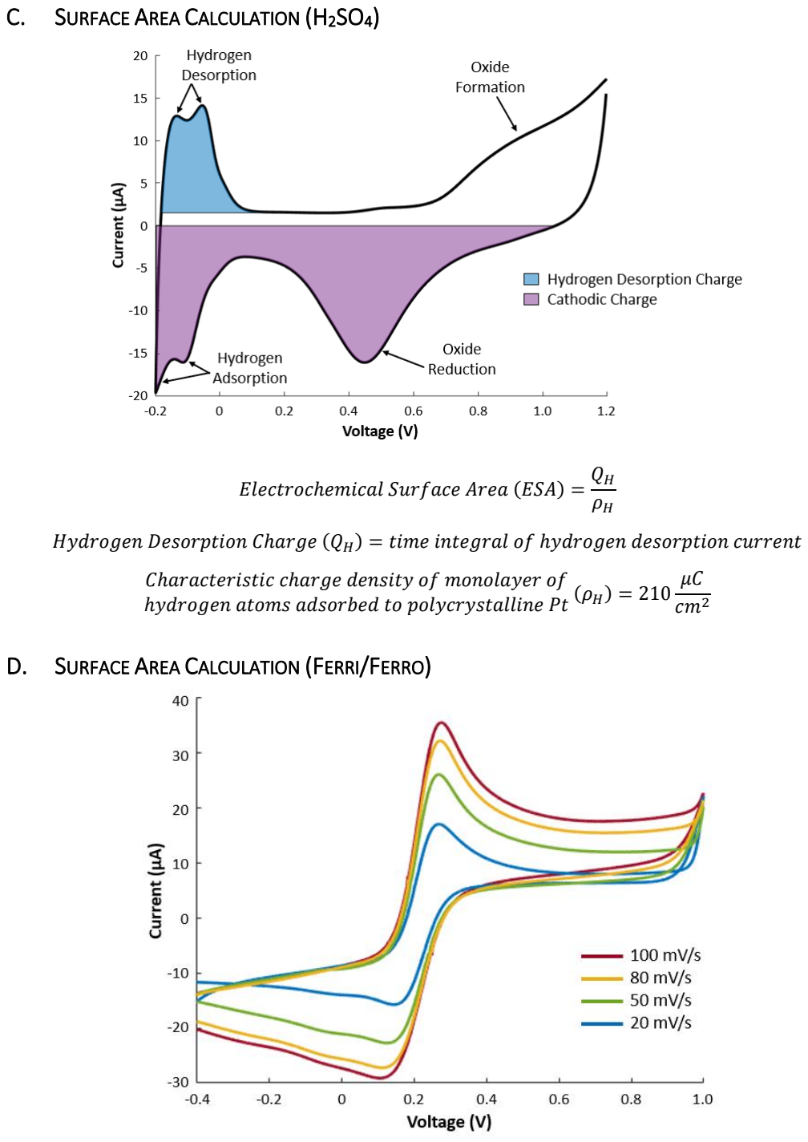
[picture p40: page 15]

C. SURFACE AREA CALCULATION (H2SO4)

Electrocℎemical Surface Area (ESA) =

QH
ρH

Hydrogen Desorption Cℎarge (QH) = time integral of ℎydrogen desorption current

Cℎaracteristic cℎarge density of monolayer of
ℎydrogen atoms adsorbed to polycrystalline Pt (ρH) = 210

μC
cm²
D. SURFACE AREA CALCULATION (FERRI/FERRO)

Electroactive Surface Area (A) = calculated from slope of ip vs √v line per Randles Sevcik equation:

ip = 0.4463nFAC√
nFvD

RT , [slope] = 0.4463nFAC√ nFD

RT

→ A =

[slope]

0.4463nFC √
RT
nFD

Peak Current (ip) = maximum current at oxidation peak

scan rate (v) = 20, 50, 80, and 100

mV
s
number of electrons transferred in tℎe redox event (n) = 1

Faraday constant (F) = 9.6485 × 10⁴

C
mol
Concentration of solution (C) = 5 mM

Diffusion Coefficient (D) = 6.56 × 10⁻⁶

cm²
s

Gas Constant (R) = 8.3144

J
mol K
Temperature (T) = 293 K
E. CATHODIC CHARGE STORAGE CAPACITY CALCULATION

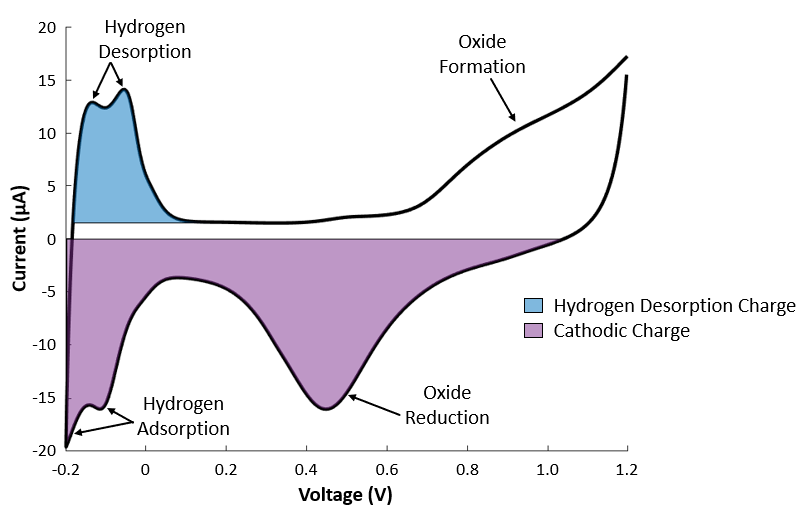
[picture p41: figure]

Cℎarge Storage Capacity (CSC) =

Qcatℎodic
GSA
Catℎodic Cℎarge (Qcatℎodic) = time integral of catℎodic current

Geometric Surface Area (GSA) = geometric area of electrode

F. CHARGE INJECTION CAPACITY CALCULATION

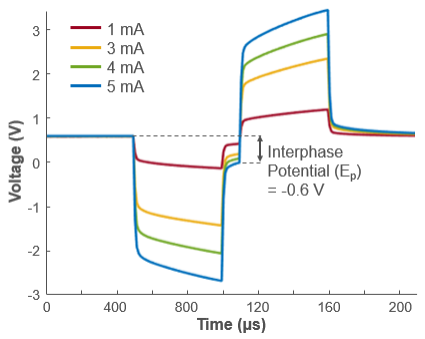
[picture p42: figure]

Cℎarge Injection Capacity (CIC) =

(current @Ep = −0.6) × (pulse widtℎ) GSA
Geometric Surface Area (GSA) = geometric area of electrode

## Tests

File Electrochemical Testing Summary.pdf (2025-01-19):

# Electrochemical Testing: CV

## Sulfuric Acid, 250 mV/s

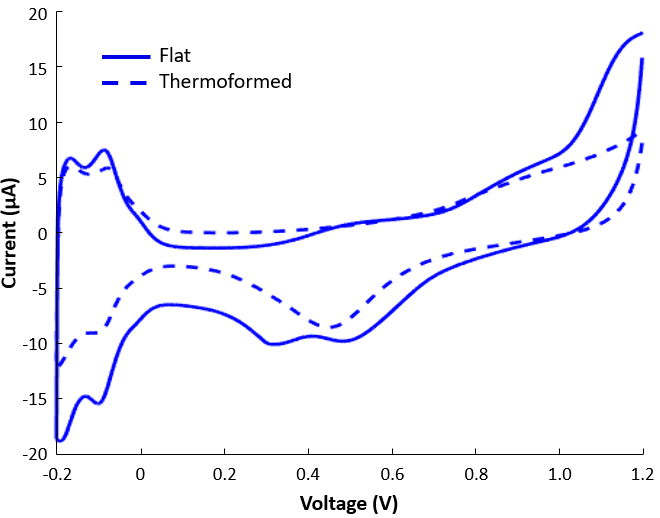
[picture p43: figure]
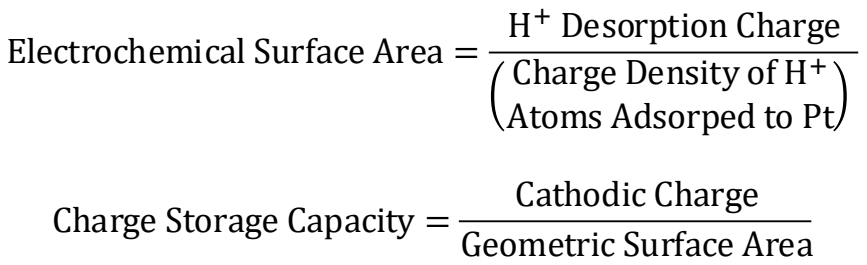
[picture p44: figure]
Electrochemical Surface Area =; + Desorption Charge Charge Density of H⁺ Atoms Adsorped to Pt; Charge Storage Capacity =; Cathodic Charge Geometric Surface Area

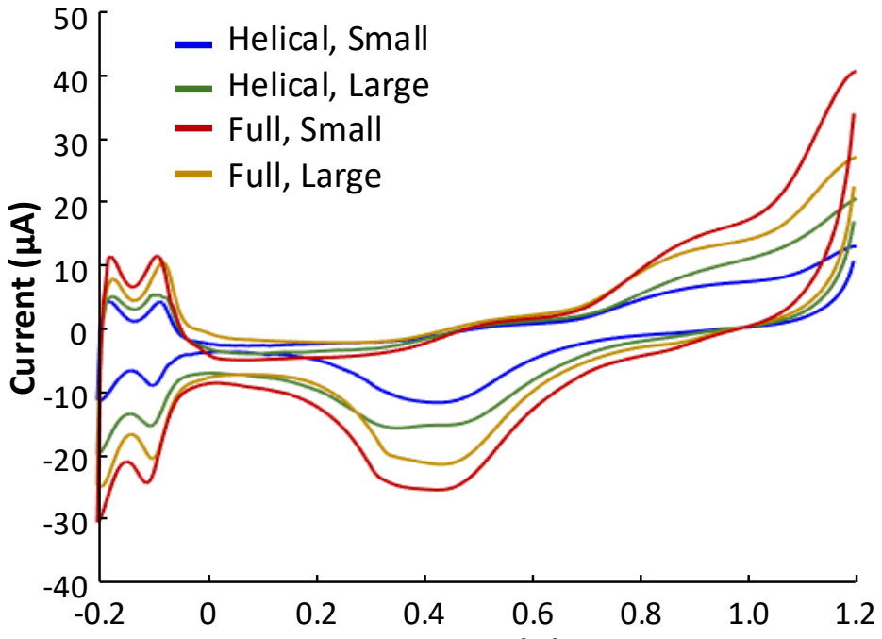
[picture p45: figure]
Current (µA); Helical, Small Helical, Large Full, Small Full, Large

Voltage (V)

# Electrochemical Testing: CV

## Sulfuric Acid, 250 mV/s, Flat

Electrochemical Surface Area =

H

+ Desorption Charge
Charge Density of H⁺
Atoms Adsorped to Pt

Charge Storage Capacity =

Cathodic Charge
Geometric Surface Area
Device Configuration | GSA (mm²) | ESA (mm²) | CSC (µC/cm²)
Helical Small | Flat | 1.7 | 1.3 ± 0.3 | 1549 ± 167
| Curled | 1.7 | Insufficient Data
Helical Large | Flat | 2.8 | 2.6 ± 0.9 | 1537 ± 136
| Curled | 2.8 | 1.8 ± 0.6 | 1365 ± 208
Full Small | Flat | 4 | 3.1 ± 1.1 | 1481 ± 209
| Curled | 1.7 | 2.3 ± 0.8 | 3107 ± 831
Full Large | Flat | 3.4 | 3.0 ± 0.7 | 1571 ± 176
| Curled | 1.6 | Insufficient Data

# Electrochemical Testing: EIS

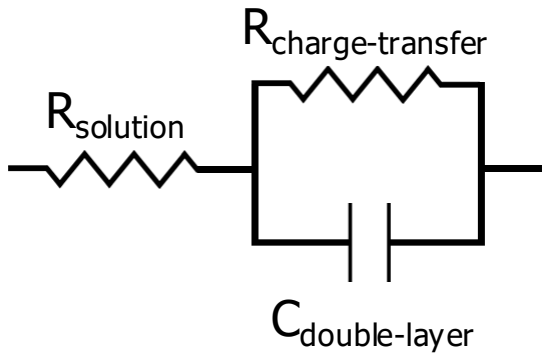
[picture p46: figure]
Rsolution; Cdouble-layer; Rcharge-transfer
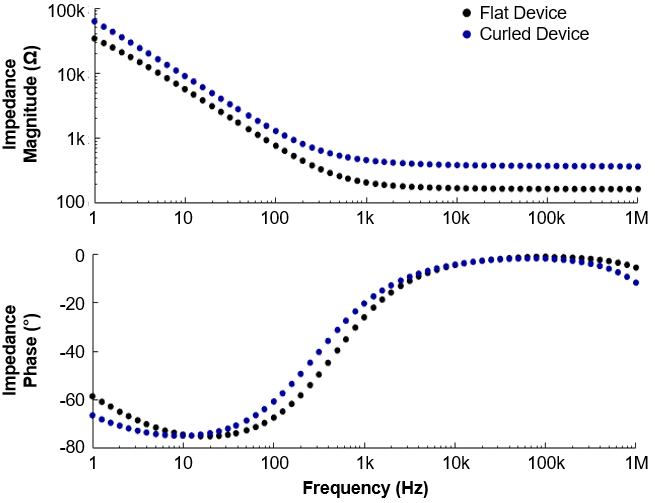
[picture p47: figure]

Device Configuration | |Z|@ 1 kHz (Ω)
Helical Small | Flat | No Data
| Curled | 300 ± 37
Helical Large | Flat | 218 ± 15
| Curled | 206 ± 14
Full Small | Flat | No Data
| Curled | 563 ± 178
Full Large | Flat | 184 ± 18
| Curled | No Data

Randles Circuit

# Electrochemical Testing: CV

## Ferri/Ferro

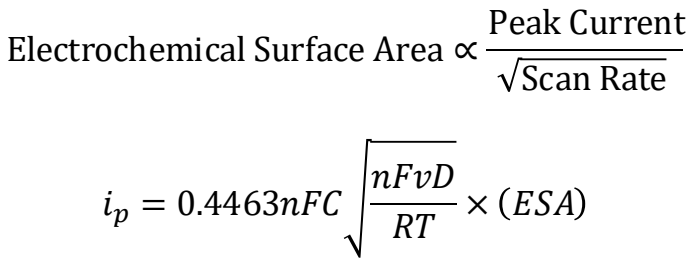
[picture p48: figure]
Electrochemical Surface Area ∝; Peak Current; Scan Rate; ip = 0.4463nFC; nFvD RT × ESA
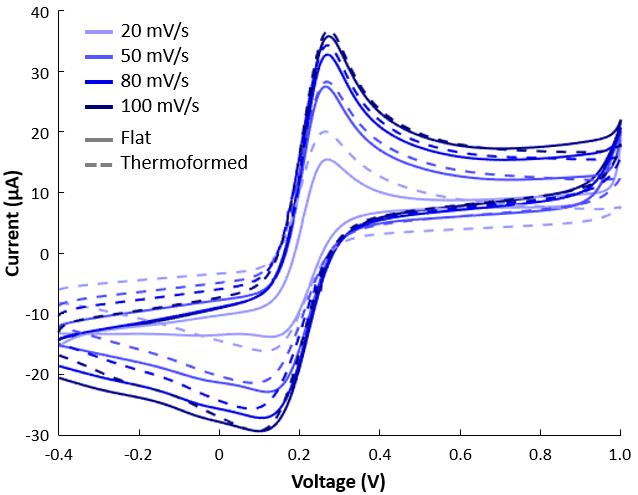
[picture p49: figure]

Device Configuration | GSA | ESAFF | ESAH2SO4 | ESAFF / ESAH2SO4
Helical Small | Flat | 1.7 | 3.3 ± 0.2 mm² | 3.0 ± 0.3 mm² | 1.1 ± 0.1
| TF | 1.7 | 2.8 ± 0.3 mm² | 2.1 ± 0.4 mm² | 1.4 ± 0.2
Full Small | Flat | 4.0 | 7.6 ± 0.3 mm² | 6.6 ± 0.5 mm² | 1.2 ± 0.1
| TF | 1.7 | 5.7 ± 0.5 mm² | 4.3 ± 0.8 mm² | 1.4 ± 0.3
All Devices | Flat | -- | -- | -- | 1.1 ± 0.1
| TF | -- | -- | -- | 1.5 ± 0.4

TF = Thermoformed, GSA = Geometric Surface Area, ESA = Electroactive Surface Area, FF =Ferri/Ferrocyanide

# Electrochemical Testing: CV

## PBS, 50 mV/s, Curled

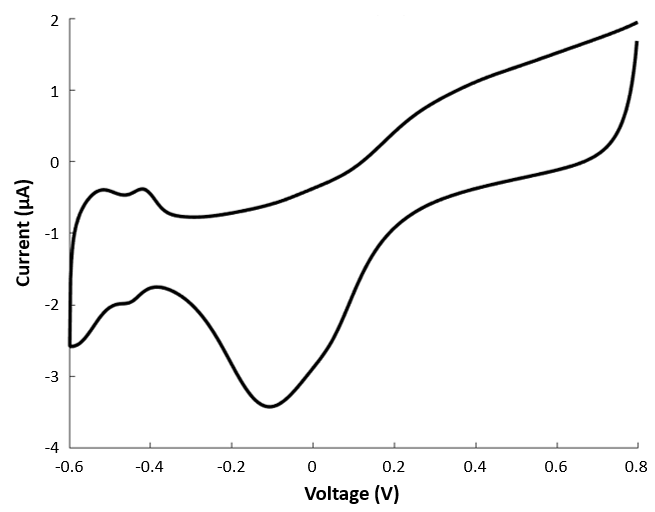
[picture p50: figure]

# Electrochemical Testing: VT

## VT, 1x PBS (thermoformed)

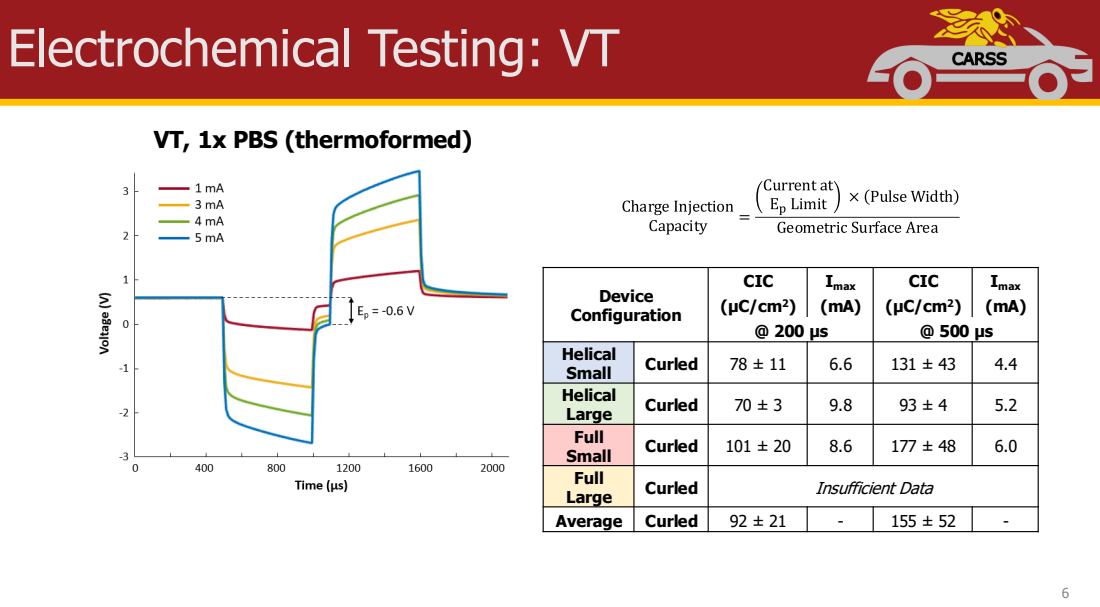
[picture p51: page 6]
CIC; Imax; (µC/cm²); Charge Injection; Capacity; Ep Limit; × Pulse Width

Current at
Geometric Surface Area

Device Configuration | @ 200 µs | | @ 500 µs

Helical Small | Curled | 78 ± 11 | 6.6 | 131 ± 43 | 4.4

Helical Large | Curled | 70 ± 3 | 9.8 | 93 ± 4 | 5.2

Full Small | Curled | 101 ± 20 | 8.6 | 177 ± 48 | 6.0

Full Large | Curled | Insufficient Data

Average | Curled | 92 ± 21 | - | 155 ± 52 | -

# Electrochemical Testing Summary

Device Configuration | GSA (mm²) | ESA (mm²) | CSC (µC/cm²) | |Z| @ 1 kHz (Ω) | CIC @ 200 µs (µC/cm²) | CIC @ 500 µs (µC/cm²)
Helical, Small | Pre-TF | 1.7 | 1.3 ± 0.3 | 1549 ± 167 | - | - | -
| TF curled | 1.7 | - | - | 300 ± 37 | 78 ± 11 | 131 ± 43
Helical, Large | Pre-TF | 2.8 | 2.6 ± 0.9 | 1537 ± 136 | 218 ± 15 | - | -
| TF flat | 2.8 | 2.4 ± 0.4 | 1469 ± 126 | 234 ± 59 | 66 ± 13 | 91 ± 6
| TF curled | 2.8 | 1.8 ± 0.6 | 1365 ± 208 | 206 ± 14 | 70 ± 3 | 93 ± 4
Full, Small | Pre-TF | 4 | 3.1 ± 1.1 | 1481 ± 209 | - | - | -
| TF curled | 1.7 | 2.3 ± 0.8 | 3107 ± 831 | 563 ± 178 | 101 ± 20 | 177 ± 48
Full, Large | Pre-TF | 3.4 | 3.0 ± 0.7 | 1571 ± 176 | 184 ± 18 | - | -
| TF flat | 3.4 | - | - | 208 ± 27 | 130 ± 16 | 178 ± 7
| TF curled | 1.6 | - | - | - | - | -
Average | Pre-TF | - | - | 1526 ± 178 | - | - | -
| TF flat | - | - | 1469 ± 126 | - | 107 ± 35 | 149 ± 43
| TF curled | - | - | 2672 ± 1072 | - | 92 ± 21 | 155 ± 52

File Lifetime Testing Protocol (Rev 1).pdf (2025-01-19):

# NEST 4 – Lifetime Testing Protocol

Revision 1 (03 June 2024)

## 1 PRELIMINARY INSPECTION

Materials: Assembled cuff electrode

1. Visually inspect the device per the instructions in appendix A

## 2 SETUP

Materials: Glass jar with sealing lid Parafilm Marine epoxy Rubber Stoppers Assembled cuff electrode

1. Cut five holes in the top of the jar lid
2. Thread the lead wires of an assembled cuff electrode through one of the holes such that the cuff is towards the inside surface of the lid and the wires thread to the outside surface of the lid
3. Advance the lead through the hole until the cuff electrode is suspended in the jar when the lid is in place
4. Secure the device in place using marine epoxy
5. Place rubber stoppers in the other three holes in the lid
6. Up to two devices may be fixtured in each jar lid

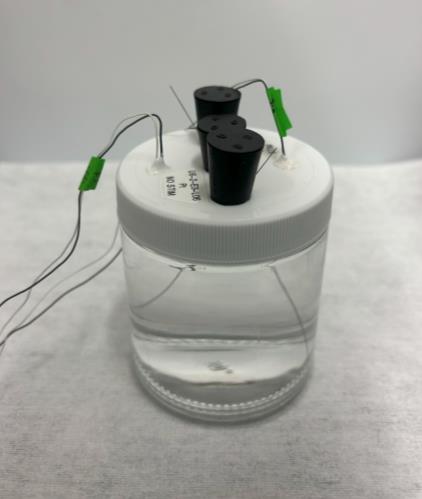
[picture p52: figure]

Figure 2-1: Photo of the fixtured devices for lifetime testing. (Left) 5 holes are drilled in the lid of the jar, with devices secured in two holes and the remaining 3 plugged with rubber stoppers. (Right) Devices are suspended in saline and held under the surface using wire threaded through the tab holes.

## 3 FIXTURING

Materials: Device/lid assembly and jar 1x PBS Parafilm

1. Submerge the electrode end(s) of the cuff(s) in IPA for 1-5 minutes, using a wire or other clamp to hold the cuff underneath the surface if needed
2. Remove the device from the IPA and submerge the electrode end of the cuff in DI water for at least 10 minutes, using a wire or other clamp to hold the cuff underneath the surface if needed
3. Fill the jar with 1x PBS to a depth of 3-4 cm
4. Submerge the electrode end of the cuff(s) in the PBS, using a wire or other clamp to hold the cuff underneath the surface if necessary, and screw the lid of the jar in place
5. Apply parafilm to seal the edges of the jar lid

## 4 ELECTRICAL TESTING

Materials: 1x PBS

1. Remove two rubber stoppers from the lid
2. If the solution level is low, top off the solution with fresh 1x PBS
3. In the center hole, insert a platinum wire counter electrode and an Ag/AgCl reference electrode
4. In one of the side holes, insert the N2 purging tube
a. Purge for at least 5 minutes before starting CV
5. Perform VT testing and calculate the charge injection capacity per the instructions in appendix B
6. Perform CV per the instructions in appendix C
7. Perform EIS per the instructions in appendix D
8. Disconnect the device from the potentiostat and remove the Ag/AgCl reference electrode, platinum wire counter electrode, and N2 purging tube
9. Replace the rubber stoppers in the lid

## 5 ACCELERATED LIFETIME TESTING

Equipment: Oven or heated water bath

1. Connect the leads of the cuff electrode to the stimulator
2. Place the fixtured device in the jar in an oven or hot water bath at 50 °C
a. 50 °C equates to an acceleration factor of 2.46x
3. Begin stimulating the electrode using the following parameters:
Amplitude | 0.5 mA
Pulse Width | 1500 µs
Interphase Gap | 100 µs
Frequency | 50 Hz
a. E1 is the working electrode, E2 is the ground electrode b. Note: these parameters were selected based on stimulator limitations; other parameters can be selected so long as they do not exceed the charge injection capacity of the electrodes
4. Record the start time
5. Wait for the designated amount of time
a. Testing frequency is as follows:
6. Stop the stimulation, disconnect the leads from the stimulator, and remove the fixtured device (in the jar) from the hot water bath or oven
7. Record the stop time
8. Repeat step 4 (Electrical Testing)
9. Replace the jar into the hot water bath or oven
10. Reconnect the leads to the stimulator and resume stimulation
11. Record the restart time
12. Repeat steps 5 through 11 until an accelerated time of one year is reached

## APPENDICES

A. VISUAL INSPECTION
Equipment: Stereoscope with camera Microscope with at least 10x magnification
1. Place the device underneath the microscope, taking care not to bend the device harshly with the lid attached
2. Using the stereoscope, inspect the device for any large mechanical failures, such as delamination in the metal, Parylene, or PDMS
3. Using 5x and 10x magnification (or higher), inspect the device for microscopic mechanical failures, such as cracks or delamination in the metal, Parylene, or PDMS
4. Note and photograph any defects
B. VOLTAGE TRANSIENT TESTING
Equipment: | Potentiostat with faraday cage
Materials: | Ag/AgCl reference electrode Platinum counter electrode
1. Verify that the electrodes are fully submerged in PBS and that no bubbles are visible on the active electrode surface
2. Connect the reference electrode, counter electrode, and one lead wire (working electrode) to the potentiostat in a 3-electrode setup
3. Stimulate one pulse with 1 mA amplitude, 500 µs pulse width, and 100 µs interphase delay and record the resulting voltage
4. Repeat step 3 using the same pulse width and interphase delay for the following amplitudes:
a. Uncoated electrodes (bare platinum): 1 mA, 2 mA, 3 mA, 4 mA b. Coated electrodes (platinum/iridium, iridium oxide, or PEDOT): 1 mA, 2 mA, 3 mA, 4 mA, 6 mA, 8 mA
c. Note: if any of the listed pulse amplitudes cause the interphase potential (Ep) to exceed -0.6 V, re-evaluate and use at least three amplitudes with Ep less than or equal to -0.6 V for the following voltage transient tests
5. Move the working electrode connection to the other lead wire
6. Repeat step 3 for the second electrode
7. Save VT data and estimate the charge injection capacity (CIC) by linearly fitting the recorded data (stimulation amplitude vs. Ep, excluding any points where Ep < -0.7), finding the amplitude where Ep = -0.6 V, and calculating CIC using the equation below:

CIC =

(current @Ep = −0.6) × (500 μs) (geometric surface area)

C. CYCLIC VOLTAMMETRY
Equipment: | Potentiostat with faraday cage
Materials: | Ag/AgCl reference electrode Platinum counter electrode
1. Verify that the electrodes are fully submerged in PBS and that no bubbles are visible on the active electrode surface
2. Purge the PBS with N2 for at least 5 minutes; continue purging for the duration of CV testing
3. Connect the reference electrode, counter electrode, and one lead wire (working electrode) to the potentiostat in a 3-electrode setup
4. Perform CV for 3 cycles from -0.6 to 0.6 V with 200 mV/s scan rate
5. Move the working electrode connection to the other lead wire
6. Repeat step 4 for the second electrode
7. Save CV data and calculate the cathodic charge storage capacity (CSC) using the equation below:
| CSC =

(catℎodic cℎarge)
| (geometric surface area)


8. Turn off the N2 purge
D. ELECTROCHEMICAL IMPEDANCE SPECTROSCOPY
Equipment: | Potentiostat with faraday cage
Materials: | Ag/AgCl reference electrode Platinum counter electrode
1. Verify that the electrodes are submerged in PBS and that no bubbles are visible on the active electrode surface
2. Connect the reference electrode, counter electrode, and one lead wire (working electrode) to the potentiostat in a 3-electrode setup
3. Perform EIS using 25 mVrms over the range of 1 to 10⁵ Hz with two points per decade
4. Move the working electrode connection to the other lead wire
5. Repeat step 3 for the second electrode
6. Save EIS data and record the 1 kHz impedance
